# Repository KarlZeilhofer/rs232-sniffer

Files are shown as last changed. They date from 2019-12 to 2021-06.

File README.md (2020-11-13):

RS232 Sniffer
=============
KiCad Projekt der HTL-Steyr. 

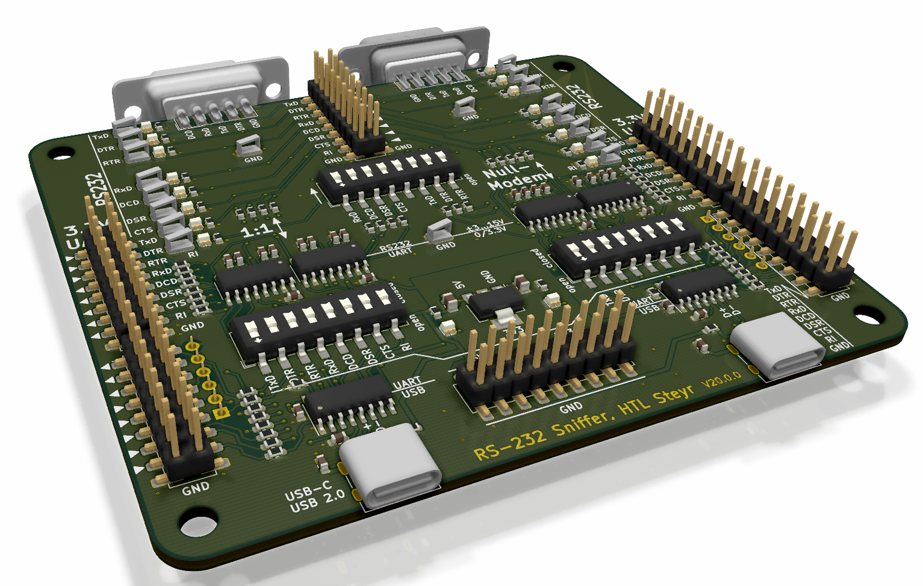
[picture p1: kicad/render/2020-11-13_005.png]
KiCad 3D Rendering


# Features
* MAX3232 für Pegelwandlung von 3.3 V auf RS232 (+-3...15 V)
* UART-Eingänge sind 5V-tolerant
* D-Sub9 Buchse Richtung PC (DTE)
* D-Sub9 Stecker Richtung Gerät (Modem, DCE)
* 2x USB-C Buchse (USB 2.0)
* 2x CH340 USB-UART-Umsetzer
* AM1117-3.3 (Linearregler für 3.3 V aus der 5V USB-Spannung)
* Signal-LEDs (grün = logisch High, rot = logisch Low)
* UART-Stiftleisten für Mikrocontroller
* Programmierbuchse für ESP32/ESP8266

# Anwendungsfälle
## RS232-Sniffer
RS232-Signale werden über D-Sub durchgeleitet. Man sieht dabei die Signal-LEDs entsprechend leuchten/blinken. 
Über die beiden USB-Anschlüsse bzw. die UART-Stiftleisten können die Daten aus beiden Richtungen mitgehorcht werden

## Protokollumsetzer
Die Verbindung der beiden D-Sub Steckverbinder kann aufgetrennt werden, und die Daten können über eine MCU oder einen PC umgeleitet werden. 
Somit können Protokolle angepasst werden bzw. Daten manipuliert werden. 

## USB-UART Adapter
Solche sind zwei Stück verbaut und können auch dirket als solche verwendet werden. 

# Hinweise
## Fertigung
* SMD-Schablone: 120um Dicke, 25mm umlaufender Rand für Pastendrucker
* Leiterplatte: 2 Layer, je 35um Cu, 103x90mm, d=1.6mm, beidseitig Bestückungsdruck
* Lötstopfreistellung: 51um
* min. Lötstopstegbreite: 100um
* Pastenreduktion: umlaufend 40um
* Durchkontaktierungen: blank (nicht mit Lötstopplack bedeckt)

## Besonderes
* Pads der USB-Buchsen wurden minimal verschmälert, um einen Lötstopplack zwischen die Pads zu bekommen.

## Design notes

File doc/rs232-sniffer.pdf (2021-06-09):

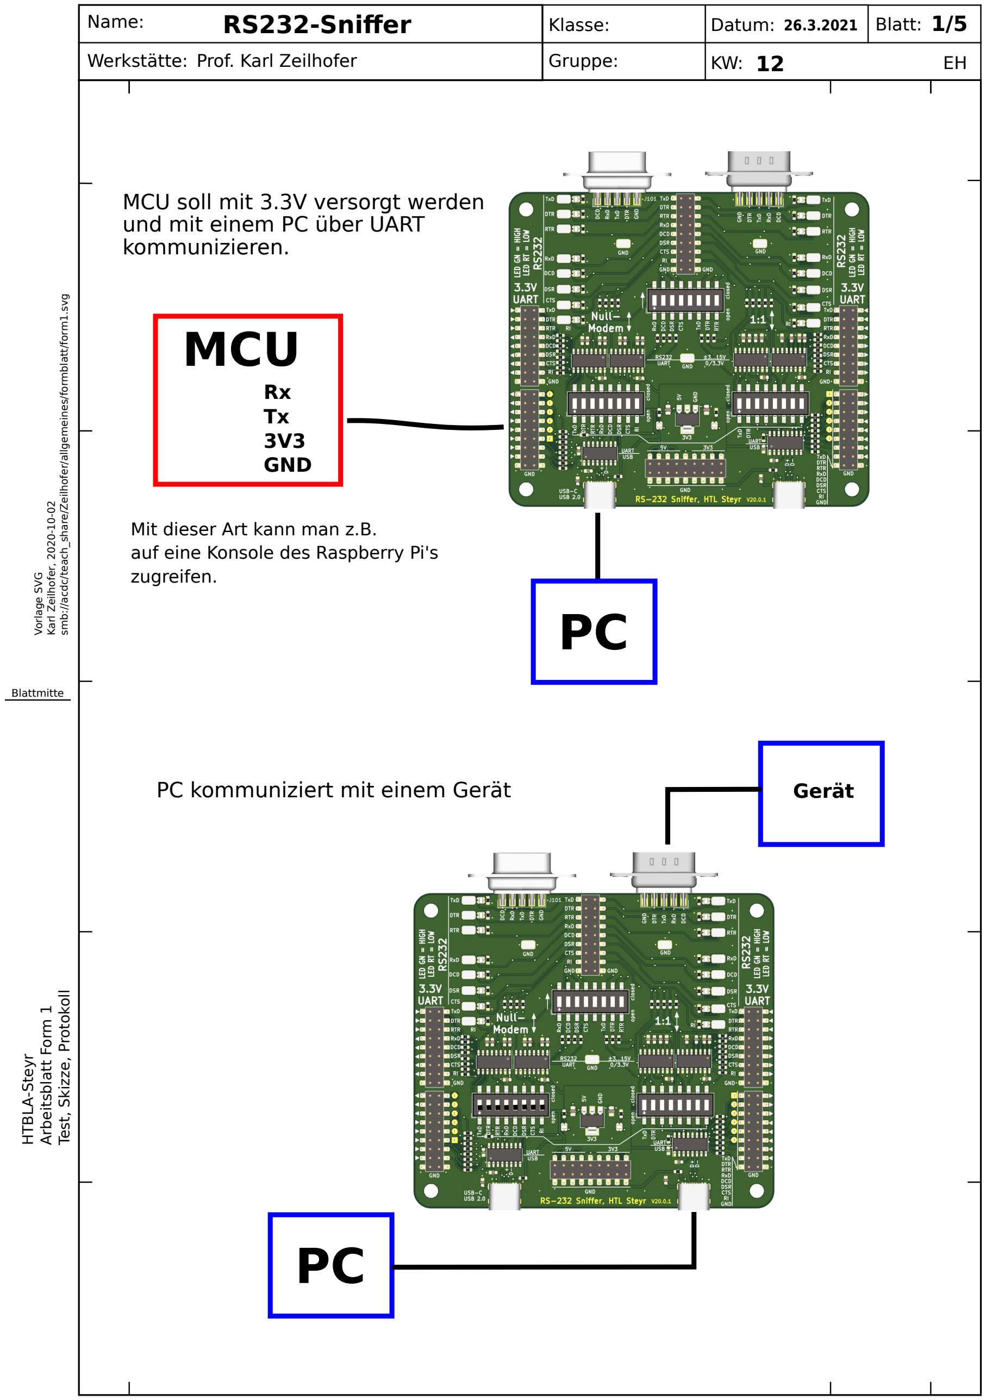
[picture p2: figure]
HTBLA-Steyr; Arbeitsblatt Form 1; Test, Skizze, Protokoll; Vorlage SVG; Karl Zeilhofer, 2020-10-02; Blattmitte; MCU; Rx Tx 3V3 GND; MCU soll mit 3.3V versorgt werden und mit einem PC über UART kommunizieren.; Gerät; PC kommuniziert mit einem Gerät; Mit dieser Art kann man z.B. auf eine Konsole des Raspberry Pi's zugreifen.

Name: RS232-Sniffer | Klasse: | 26.3.2021 Datum: | 1/5 Blatt:
Werkstätte: Prof. Karl Zeilhofer | Gruppe: | KW: 12 EH

smb://acdc/teach_share/Zeilhofer/allgemeines/formblatt/form1.svg

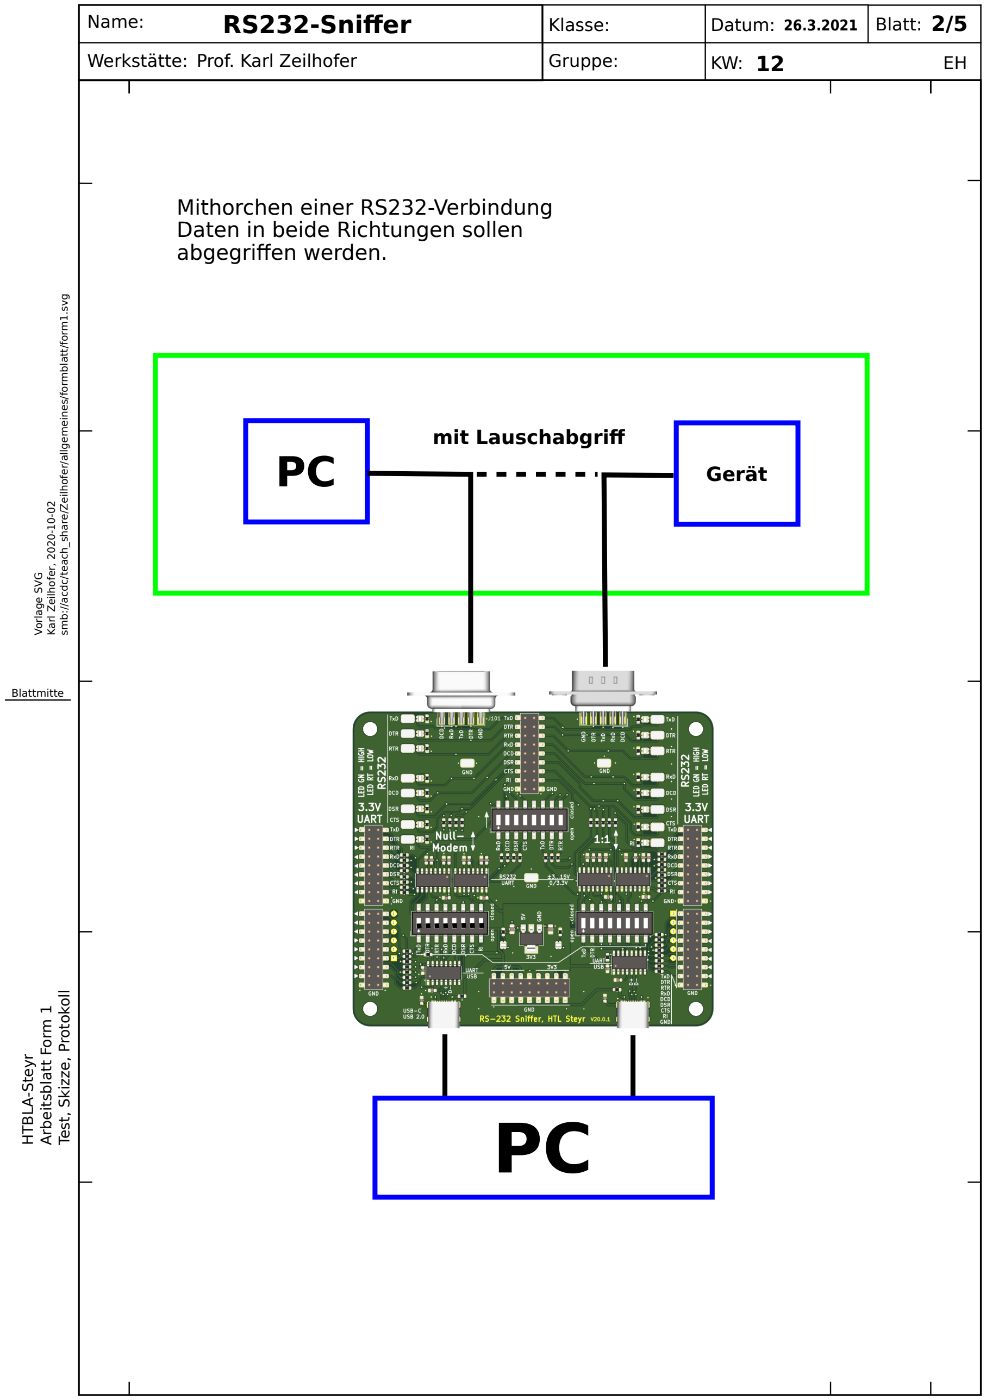
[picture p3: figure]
HTBLA-Steyr; Arbeitsblatt Form 1; Test, Skizze, Protokoll; Vorlage SVG; Karl Zeilhofer, 2020-10-02; Blattmitte; Gerät; mit Lauschabgriff; Mithorchen einer RS232-Verbindung Daten in beide Richtungen sollen abgegriffen werden.

smb://acdc/teach_share/Zeilhofer/allgemeines/formblatt/form1.svg

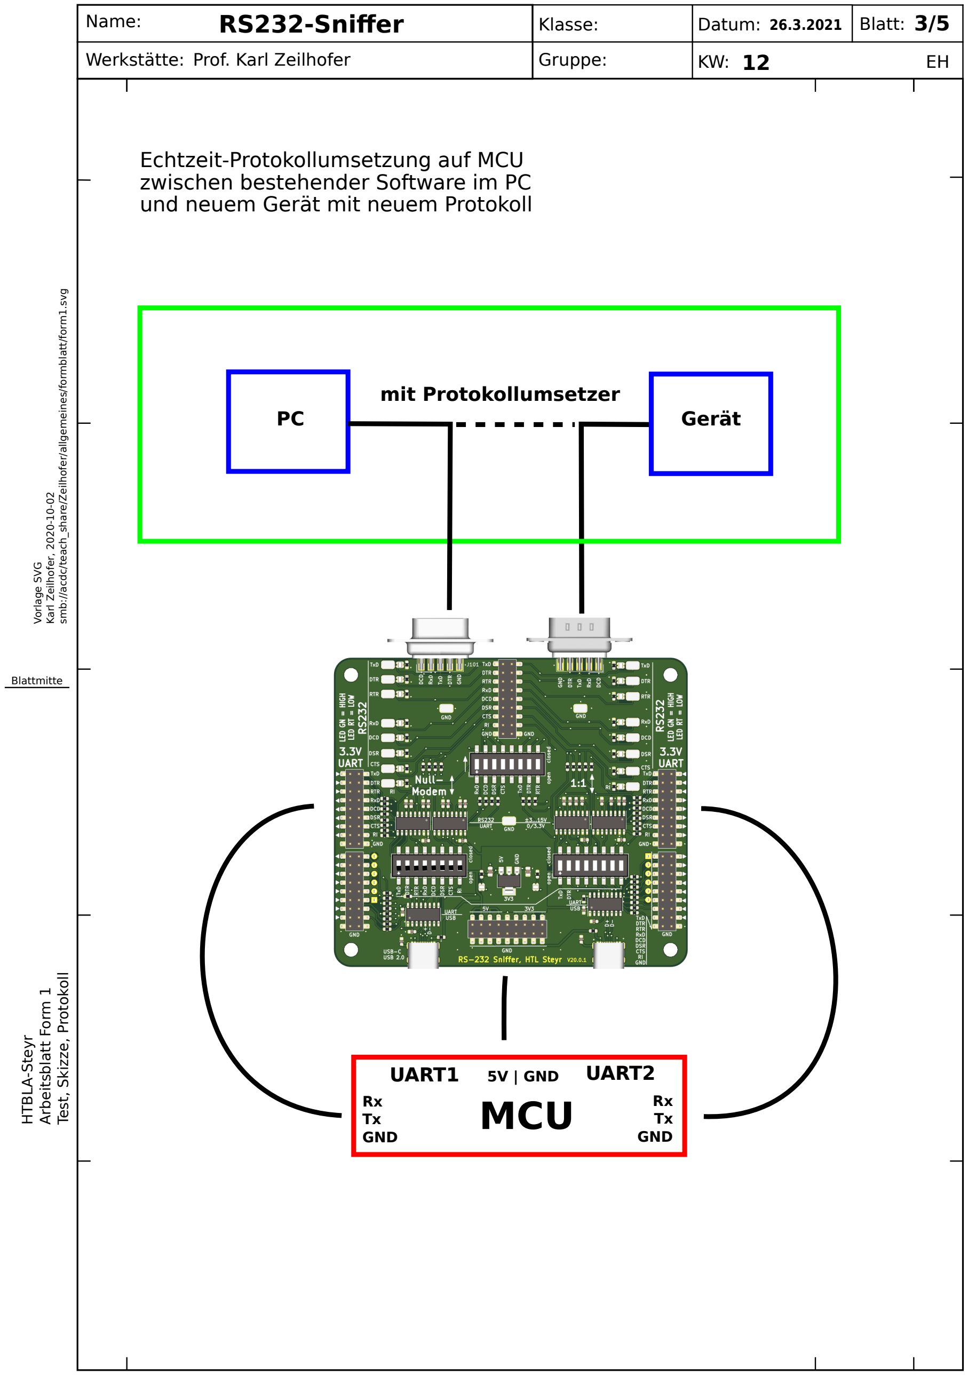
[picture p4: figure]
HTBLA-Steyr; Arbeitsblatt Form 1; Test, Skizze, Protokoll; Vorlage SVG; Karl Zeilhofer, 2020-10-02; Blattmitte; Echtzeit-Protokollumsetzung auf MCU zwischen bestehender Software im PC und neuem Gerät mit neuem Protokoll; MCU; Gerät; UART1; UART2; mit Protokollumsetzer; Rx Tx GND; 5V | GND

smb://acdc/teach_share/Zeilhofer/allgemeines/formblatt/form1.svg

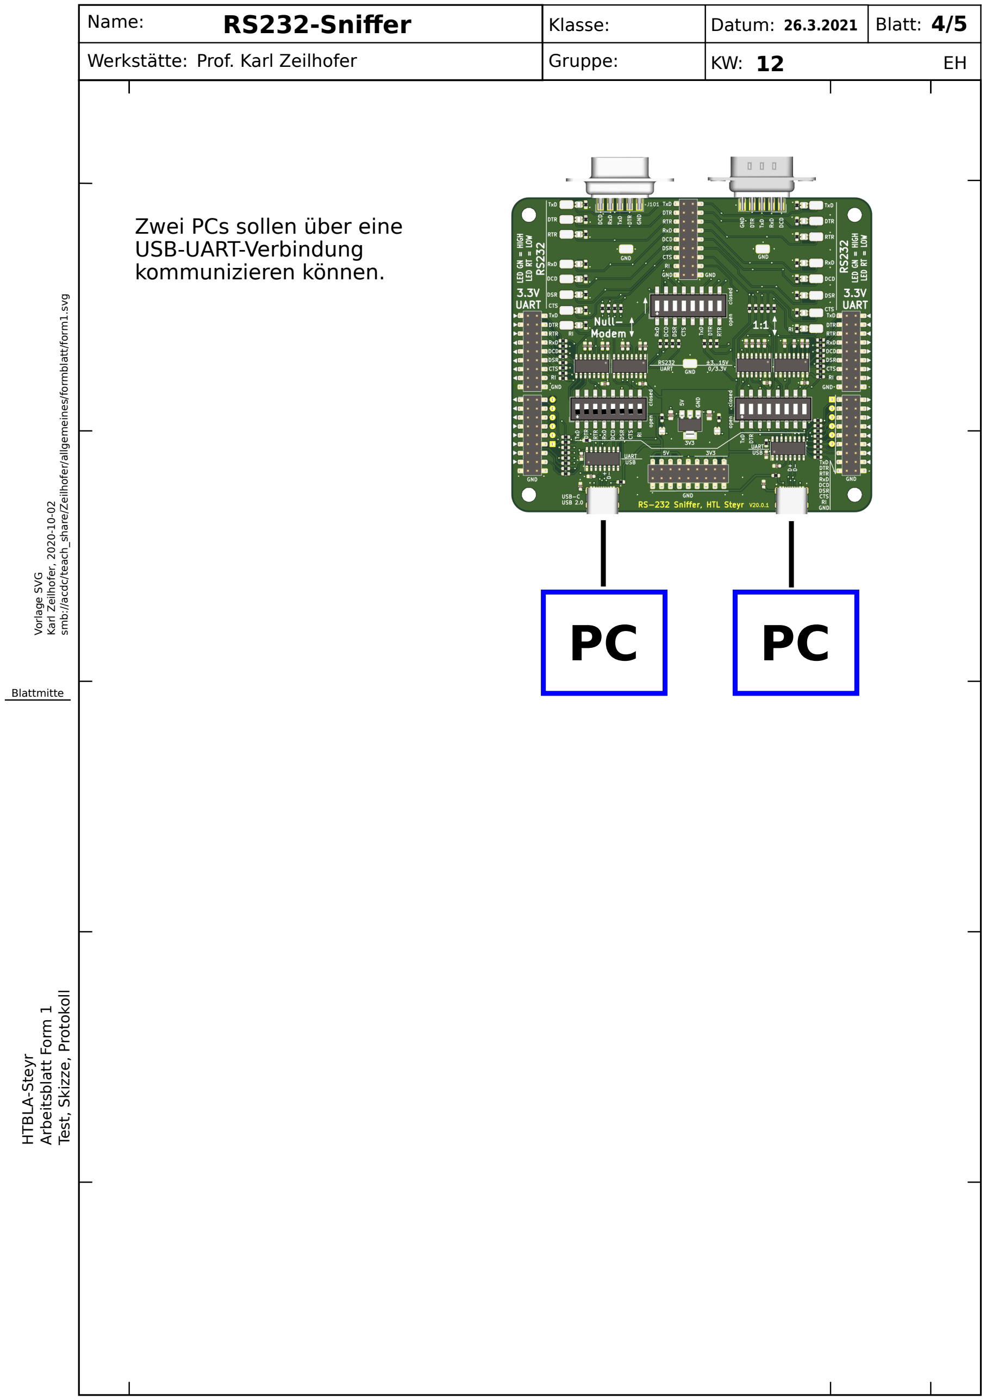
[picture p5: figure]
HTBLA-Steyr; Arbeitsblatt Form 1; Test, Skizze, Protokoll; Vorlage SVG; Karl Zeilhofer, 2020-10-02; Blattmitte; Zwei PCs sollen über eine USB-UART-Verbindung kommunizieren können.

smb://acdc/teach_share/Zeilhofer/allgemeines/formblatt/form1.svg

5/5

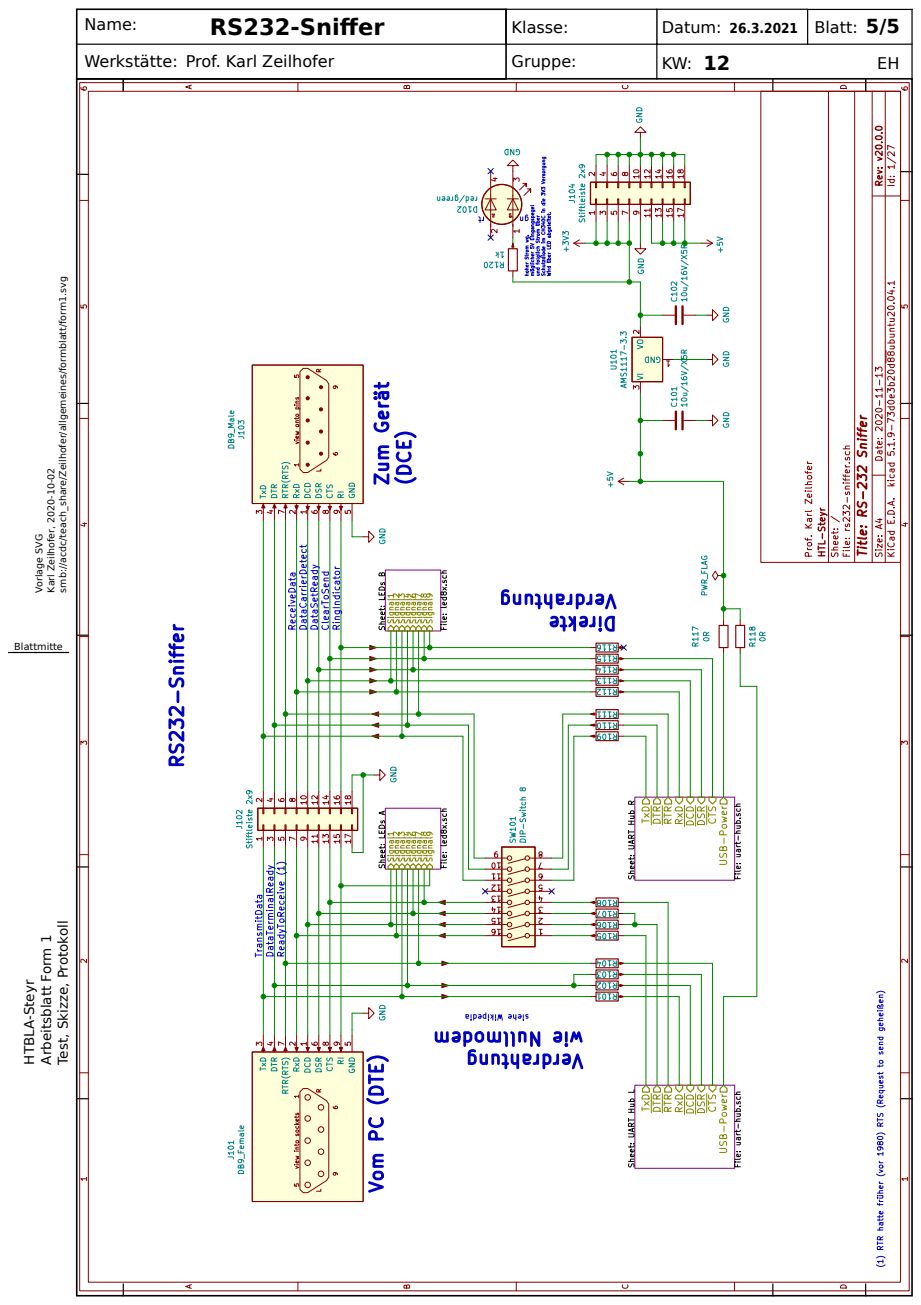
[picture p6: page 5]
HTBLA-Steyr; Arbeitsblatt Form 1; Vorlage SVG; Karl Zeilhofer, 2020-10-02; Blattmitte

smb://acdc/teach_share/Zeilhofer/allgemeines/formblatt/form1.svg

Test, Skizze, Protokoll

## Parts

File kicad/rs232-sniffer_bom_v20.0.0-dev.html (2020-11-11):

Source File | rs232-sniffer.sch
BoM Date | 2020-10-13T15:02:40 CEST
Schematic Version | v20.0.0-dev
Schematic Date | 2020-10-09
PCB Variant | [u'default']
KiCad Version | Eeschema 5.1.6-c6e7f7d~87~ubuntu18.04.1
Component Groups | 19
Component Count (per PCB) | 146
Fitted Components (per PCB) | 146
Number of PCBs | 1
Total Component Count (for 1 PCBs) | 146
 | Description | Part | References | Value | Footprint | Quantity Per PCB | Datasheet | Weblink | DistOrderNr | PriceForQty | PriceEUR | Distributor | ManPartNr | Manufacturer | Notes
1 | Unpolarized capacitor | C | C2501 C2502 C2503 C2504 C2505 C2506 C2601 C2602 C2603 C2604 C2605 C2606 C2607 C2608 C2609 C2610 C2701 C2702 C2703 C2704 C2705 C2706 C2707 C2708 C2709 C2710 | 100n | C_0603_1608Metric | 26 | https://datasheet.lcsc.com/szlcsc/1811151136_Walsin-Tech-Corp-0603B104K160CT_C80516.pdf | https://lcsc.com/product-detail/Multilayer-Ceramic-Capacitors-MLCC-SMD-SMT_Walsin-Tech-Corp-0603B104K160CT_C80516.html | C80516 | 500 | 0.002141 | LCSC | 0603B104K160CT | Walsin Tech Corp | 100nF ±10% 16V X7R
2 | Unpolarized capacitor | C | C101 C102 | 10u/16V/X5R | C_0805_2012Metric | 2 | https://datasheet.lcsc.com/szlcsc/1811151151_Samsung-Electro-Mechanics-CL21A106KOQNNNE_C1713.pdf | https://lcsc.com/product-detail/Multilayer-Ceramic-Capacitors-MLCC-SMD-SMT_SAMSUNG_CL21A106KOQNNNE_10uF-106-10-16V_C1713.html | C1713 | 200 | 0.011386 | LCSC | CL21A106KOQNNNE | Samsung | 10uF ±10% 16V X5R
3 | Dual LED, cathodes on pins 3 and 4 | LED_Dual_AACC | D101 D102 D301 D401 D501 D601 D701 D801 D901 D1001 D1201 D1301 D1401 D1501 D1601 D1701 D1801 D1901 | red/green | LED_LiteOn_LTST-C195KGJRKT | 18 | https://datasheet.lcsc.com/szlcsc/1811100910_Lite-On-LTST-C195KGJRKT_C125104.pdf | https://lcsc.com/product-detail/Light-Emitting-Diodes-LED_Lite-On-LTST-C195KGJRKT_C125104.html | C125104 | 1000 | 0.023 | LCSC | LTST-C195KGJRKT | LiteOn | Dual LED
4 | Virtual Item for accessories which should be listed in the BOM | Item | Item1 Item2 Item3 Item4 Item5 Item6 Item7 Item8 | Jumper | ~ | 8 | https://datasheet.lcsc.com/szlcsc/1811132212_BOOMELE-Boom-Precision-Elec-C5305_C5305.pdf | https://lcsc.com/product-detail/Shunts-Jumpers_BOOMELE-Boom-Precision-Elec-C5305_C5305.html | C5305 | 500 | 0.00319 | LCSC | C5305 | BOOMELE(Boom Precision Elec) | Jumper, 2.54mm
5 | Generic connector, single row, 01x06, script generated (kicad-library-utils/schlib/autogen/connector/) | Conn_01x06 | J2402 J2405 | Buchsenleiste 1x6, horizontal | PinSocket_1x06_P2.54mm_Horizontal | 2
6 | 9-pin male D-SUB connector | RS232_DB9_Female | J101 | DB9_Female | DSUB-9_Female_EdgeMount_P2.77mm | 1 | https://datasheet.lcsc.com/szlcsc/1811081030_CONNFLY-Elec-DS1033-09FUNSiSS-CT_C75748.pdf | https://lcsc.com/product-detail/D-Sub-Connectors_D-SUB-9pin-Female-blue-Welded-wire-type-Tin-plating-Without-screws_C75748.html | C75748 | 150 | 0.063911 | LCSC | DS1033-09FUNSiSS-CT | CONNFLY Elec | RS232 weiblich
7 | 9-pin male D-SUB connector | RS232_DB9_Male | J103 | DB9_Male | DSUB-9_Male_EdgeMount_P2.77mm | 1 |  | https://lcsc.com/product-detail/D-Sub-Connectors_D-SUB-9pin-Male-head-blue-Welded-wire-type-Tin-plating-Without-screws_C75746.html | C75746 | 150 | 0.059745 | LCSC | DS1033-09MUNSiSS | CONNFLY Elec | RS232 männlich
8 | Generic connector, double row, 02x09, odd/even pin numbering scheme (row 1 odd numbers, row 2 even numbers), script generated (kicad-library-utils/schlib/autogen/connector/) | Conn_02x09_Odd_Even | J102 J104 J2001 J2002 J2401 J2403 | Stiftleiste 2x9 | PinHeader_2x09_P2.54mm_Vertical_SMD | 6 |  | https://lcsc.com/product-detail/Pin-Header-Female-Header_BOOMELE-Boom-Precision-Elec-C88175_C88175.html | C88175 | 100 | 0.036 | LCSC | C88175 | BOOMELE(Boom Precision Elec) | SMD
9 | USB 2.0-only Type-C Receptacle connector | USB_C_Receptacle_USB2.0 | J2501 J2502 | USB-C/16p | USB_C_Receptacle_LCSC_C167321 | 2 | https://www.usb.org/sites/default/files/documents/usb_type-c.zip | https://lcsc.com/product-detail/USB-Connectors_Jing-Extension-of-the-Electronic-Co-C167321_C167321.html | C167321 | 100 | 0.155 | LCSC | C167321 | Jing Extension | USB-C, 16-polig, USB 2.0
10 | Resistor | R | R118 R120 | 0R | R_0603_1608Metric | 2 |  |  |  |  |  | LCSC
11 |  | R_sig | R105 R106 R107 R108 R109 R110 R111 R112 R114 R115 R116 R117 R119 R121 R122 R123 R2004 R2005 R2006 R2007 R2008 R2403 R2404 R2406 R2409 R2410 R2411 R2420 R2421 R2422 R2423 R2424 | 100R | R_0603_1608Metric | 32 | https://datasheet.lcsc.com/szlcsc/Uniroyal-Elec-0603WAJ0101T5E_C25201.pdf | https://lcsc.com/product-detail/Chip-Resistor-Surface-Mount_UNI-ROYAL-Uniroyal-Elec-0603WAJ0101T5E_C25201.html | C25201 | 1000 | 0.000563 | LCSC | 0603WAJ0101T5E | UNI-ROYAL | 100R, 5%, 100mW
12 | Resistor | R | R2501 R2502 | 100R | R_0603_1608Metric | 2 | https://datasheet.lcsc.com/szlcsc/Uniroyal-Elec-0603WAJ0101T5E_C25201.pdf | https://lcsc.com/product-detail/Chip-Resistor-Surface-Mount_UNI-ROYAL-Uniroyal-Elec-0603WAJ0101T5E_C25201.html | C25201 | 1000 | 0.000563 | LCSC | 0603WAJ0101T5E | UNI-ROYAL | 100R, 5%, 100mW
13 |  | R_sig | R113 R2001 R2002 R2003 R2401 R2402 R2405 R2407 R2408 R2412 R2413 R2414 R2415 R2416 R2417 R2418 R2419 | 1k | R_0603_1608Metric | 17 |  | https://lcsc.com/product-detail/Chip-Resistor-Surface-Mount_1KR-102-5_C103209.html | C103209 | 1000 | 0.000556 | LCSC | RTT03102JTP | RALEC | 1kΩ ±5% 0.1W ±100ppm/℃
14 | Resistor | R | R301 R401 R501 R601 R701 R801 R901 R1001 R1201 R1301 R1401 R1501 R1601 R1701 R1801 R1901 | 4k7 | R_0603_1608Metric | 16 | https://datasheet.lcsc.com/szlcsc/1809261316_RALEC-RTT03472JTP_C103662.pdf | https://lcsc.com/product-detail/Chip-Resistor-Surface-Mount_RALEC-RTT03472JTP_C103662.html | C103662 | 1000 | 0.000527 | LCSC | RTT03472JTP | RALEC | 4.7kΩ ±5% 0.1W ±100ppm/℃
15 |  | R_sig | R104 | 4k7 | R_0603_1608Metric | 1 | https://datasheet.lcsc.com/szlcsc/1809261316_RALEC-RTT03472JTP_C103662.pdf | https://lcsc.com/product-detail/Chip-Resistor-Surface-Mount_RALEC-RTT03472JTP_C103662.html | C103662 | 1000 | 0.000527 | LCSC | RTT03472JTP | RALEC | 4.7kΩ ±5% 0.1W ±100ppm/℃
16 | 8x DIP Switch, Single Pole Single Throw (SPST) switch, small symbol | SW_DIP_x08 | SW101 SW2401 SW2402 | DIP-Switch 8 | SW_DIP_SPSTx08_Slide_6.7x21.88mm_W8.61mm_P2.54mm_LowProfile | 3 | https://datasheet.lcsc.com/szlcsc/Made-in-China-HAD-08HWA-R_C4682.pdf | https://lcsc.com/product-detail/DIP-Switches_Cixi-Tonver-Elec-HAD-08HWA-R_C4682.html | C4682 | 100 | 0.262623 | LCSC | HAD-08HWA-R | Cixi Tonver Elec | SMD DIP-Switch
17 | 1A Low Dropout regulator, positive, 3.3V fixed output, SOT-223 | AMS1117-3.3 | U101 | AMS1117-3.3 | SOT-223-3_TabPin2 | 1 | http://www.advanced-monolithic.com/pdf/ds1117.pdf | https://lcsc.com/products/Dropout-Regulators-LDO_387.html?q=ams1117-3.3 | C347222 | 100 | 0.023029 | LCSC | AMS1117-3.3 | UMW Youtai Semiconductor | LDO, 3.3V
18 | USB serial converter, UART, SOIC-16 | CH340C | U2501 U2502 | CH340C | SOIC-16_3.9x9.9mm_P1.27mm | 2 | http://www.datasheet5.com/pdf-local-2195953 | https://lcsc.com/product-detail/USB-ICs_WCH-Jiangsu-Qin-Heng-CH340C_C84681.html | C84681 | 100 | 0.239 | LCSC | CH340C | WCH(Jiangsu Qin Heng) | USB-UART with internal clock
19 | 3.0V to 5.5V, Low-Power, up to 1Mbps, True RS-232 Transceivers Using Four 0.1μF External Capacitors | MAX3232 | U2601 U2602 U2701 U2702 | MAX3232 | SOIC-16_3.9x9.9mm_P1.27mm | 4 | https://datasheets.maximintegrated.com/en/ds/MAX3222-MAX3241.pdf | https://lcsc.com/product-detail/Uncategorized_HGSEMI-MAX3232EIM-TR_C434486.html | C434486 | 100 | 0.188404 | LCSC | MAX3232EIM/TR | HGSEMI | RS232 - UART Umsetzer, 3V3 oder 5V

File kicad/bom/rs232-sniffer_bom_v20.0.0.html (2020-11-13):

Source File | rs232-sniffer.sch
BoM Date | 2020-11-13T16:51:07 CET
Schematic Version | v20.0.0
Schematic Date | 2020-11-13
PCB Variant | [u'default']
KiCad Version | Eeschema 5.1.6-c6e7f7d~87~ubuntu18.04.1
Component Groups | 19
Component Count (per PCB) | 146
Fitted Components (per PCB) | 146
Number of PCBs | 1
Total Component Count (for 1 PCBs) | 146
 | Description | Part | References | Value | Footprint | Quantity Per PCB | Datasheet | Weblink | DistOrderNr | PriceForQty | PriceEUR | Distributor | ManPartNr | Manufacturer | Notes
1 | Unpolarized capacitor | C | C2501 C2502 C2503 C2504 C2505 C2506 C2601 C2602 C2603 C2604 C2605 C2606 C2607 C2608 C2609 C2610 C2701 C2702 C2703 C2704 C2705 C2706 C2707 C2708 C2709 C2710 | 100n | C_0603_1608Metric | 26 | https://datasheet.lcsc.com/szlcsc/1811151136_Walsin-Tech-Corp-0603B104K160CT_C80516.pdf | https://lcsc.com/product-detail/Multilayer-Ceramic-Capacitors-MLCC-SMD-SMT_Walsin-Tech-Corp-0603B104K160CT_C80516.html | C80516 | 500 | 0.002141 | LCSC | 0603B104K160CT | Walsin Tech Corp | 100nF ±10% 16V X7R
2 | Unpolarized capacitor | C | C101 C102 | 10u/16V/X5R | C_0805_2012Metric | 2 | https://datasheet.lcsc.com/szlcsc/1811151151_Samsung-Electro-Mechanics-CL21A106KOQNNNE_C1713.pdf | https://lcsc.com/product-detail/Multilayer-Ceramic-Capacitors-MLCC-SMD-SMT_SAMSUNG_CL21A106KOQNNNE_10uF-106-10-16V_C1713.html | C1713 | 200 | 0.011386 | LCSC | CL21A106KOQNNNE | Samsung | 10uF ±10% 16V X5R
3 | Dual LED, cathodes on pins 3 and 4 | LED_Dual_green-red | D101 D102 D301 D401 D501 D601 D701 D801 D901 D1001 D1201 D1301 D1401 D1501 D1601 D1701 D1801 D1901 | red/green | LED_LiteOn_LTST-C195KGJRKT | 18 | https://datasheet.lcsc.com/szlcsc/1811100910_Lite-On-LTST-C195KGJRKT_C125104.pdf | https://lcsc.com/product-detail/Light-Emitting-Diodes-LED_Lite-On-LTST-C195KGJRKT_C125104.html | C125104 | 1000 | 0.023 | LCSC | LTST-C195KGJRKT | LiteOn | Dual LED
4 | Virtual Item for accessories which should be listed in the BOM | Item | Item101 Item102 Item103 Item104 Item105 Item106 Item107 Item108 | Jumper | ~ | 8 | https://datasheet.lcsc.com/szlcsc/1811132212_BOOMELE-Boom-Precision-Elec-C5305_C5305.pdf | https://lcsc.com/product-detail/Shunts-Jumpers_BOOMELE-Boom-Precision-Elec-C5305_C5305.html | C5305 | 500 | 0.00319 | LCSC | C5305 | BOOMELE(Boom Precision Elec) | Jumper, 2.54mm
5 | Generic connector, single row, 01x06, script generated (kicad-library-utils/schlib/autogen/connector/) | Conn_01x06 | J2402 J2405 | Buchsenleiste 1x6, horizontal | PinSocket_1x06_P2.54mm_Horizontal | 2
6 | 9-pin male D-SUB connector | RS232_DB9_Female | J101 | DB9_Female | DSUB-9_Female_EdgeMount_P2.77mm | 1 | https://datasheet.lcsc.com/szlcsc/1811081030_CONNFLY-Elec-DS1033-09FUNSiSS-CT_C75748.pdf | https://lcsc.com/product-detail/D-Sub-Connectors_D-SUB-9pin-Female-blue-Welded-wire-type-Tin-plating-Without-screws_C75748.html | C75748 | 150 | 0.063911 | LCSC | DS1033-09FUNSiSS-CT | CONNFLY Elec | RS232 weiblich
7 | 9-pin male D-SUB connector | RS232_DB9_Male | J103 | DB9_Male | DSUB-9_Male_EdgeMount_P2.77mm | 1 |  | https://lcsc.com/product-detail/D-Sub-Connectors_D-SUB-9pin-Male-head-blue-Welded-wire-type-Tin-plating-Without-screws_C75746.html | C75746 | 150 | 0.059745 | LCSC | DS1033-09MUNSiSS | CONNFLY Elec | RS232 männlich
8 | Generic connector, double row, 02x09, odd/even pin numbering scheme (row 1 odd numbers, row 2 even numbers), script generated (kicad-library-utils/schlib/autogen/connector/) | Conn_02x09_Odd_Even | J102 J104 J2001 J2002 J2401 J2403 | Stiftleiste 2x9 | PinHeader_2x09_P2.54mm_Vertical_SMD_LCSC_C88175 | 6 |  | https://lcsc.com/product-detail/Pin-Header-Female-Header_BOOMELE-Boom-Precision-Elec-C88175_C88175.html | C88175 | 100 | 0.036 | LCSC | C88175 | BOOMELE(Boom Precision Elec) | SMD
9 | USB 2.0-only Type-C Receptacle connector | USB_C_Receptacle_USB2.0 | J2501 J2502 | USB-C/16p | USB_C_Receptacle_LCSC_C167321 | 2 | https://www.usb.org/sites/default/files/documents/usb_type-c.zip | https://lcsc.com/product-detail/USB-Connectors_Jing-Extension-of-the-Electronic-Co-C167321_C167321.html | C167321 | 100 | 0.155 | LCSC | C167321 | Jing Extension | USB-C, 16-polig, USB 2.0
10 | Resistor | R | R117 R118 | 0R | R_0603_1608Metric | 2 |  |  |  |  |  | LCSC
11 |  | R_sig | R101 R102 R103 R104 R105 R106 R107 R108 R109 R110 R111 R112 R113 R114 R115 R116 R2004 R2005 R2006 R2007 R2008 R2403 R2404 R2406 R2409 R2410 R2411 R2420 R2421 R2422 R2423 R2424 | 100R | R_0603_1608Metric | 32 | https://datasheet.lcsc.com/szlcsc/Uniroyal-Elec-0603WAJ0101T5E_C25201.pdf | https://lcsc.com/product-detail/Chip-Resistor-Surface-Mount_UNI-ROYAL-Uniroyal-Elec-0603WAJ0101T5E_C25201.html | C25201 | 1000 | 0.000563 | LCSC | 0603WAJ0101T5E | UNI-ROYAL | 100R, 5%, 100mW
12 | Resistor | R | R2501 R2502 | 100R | R_0603_1608Metric | 2 | https://datasheet.lcsc.com/szlcsc/Uniroyal-Elec-0603WAJ0101T5E_C25201.pdf | https://lcsc.com/product-detail/Chip-Resistor-Surface-Mount_UNI-ROYAL-Uniroyal-Elec-0603WAJ0101T5E_C25201.html | C25201 | 1000 | 0.000563 | LCSC | 0603WAJ0101T5E | UNI-ROYAL | 100R, 5%, 100mW
13 |  | R_sig | R120 R2001 R2002 R2003 R2401 R2402 R2405 R2407 R2408 R2412 R2413 R2414 R2415 R2416 R2417 R2418 R2419 | 1k | R_0603_1608Metric | 17 |  | https://lcsc.com/product-detail/Chip-Resistor-Surface-Mount_1KR-102-5_C103209.html | C103209 | 1000 | 0.000556 | LCSC | RTT03102JTP | RALEC | 1kΩ ±5% 0.1W ±100ppm/℃
14 | Resistor | R | R301 R401 R501 R601 R701 R801 R901 R1001 R1201 R1301 R1401 R1501 R1601 R1701 R1801 R1901 | 4k7 | R_0603_1608Metric | 16 | https://datasheet.lcsc.com/szlcsc/1809261316_RALEC-RTT03472JTP_C103662.pdf | https://lcsc.com/product-detail/Chip-Resistor-Surface-Mount_RALEC-RTT03472JTP_C103662.html | C103662 | 1000 | 0.000527 | LCSC | RTT03472JTP | RALEC | 4.7kΩ ±5% 0.1W ±100ppm/℃
15 |  | R_sig | R119 | 4k7 | R_0603_1608Metric | 1 | https://datasheet.lcsc.com/szlcsc/1809261316_RALEC-RTT03472JTP_C103662.pdf | https://lcsc.com/product-detail/Chip-Resistor-Surface-Mount_RALEC-RTT03472JTP_C103662.html | C103662 | 1000 | 0.000527 | LCSC | RTT03472JTP | RALEC | 4.7kΩ ±5% 0.1W ±100ppm/℃
16 | 8x DIP Switch, Single Pole Single Throw (SPST) switch, small symbol | SW_DIP_x08 | SW101 SW2401 SW2402 | DIP-Switch 8 | SW_DIP_SPSTx08_Slide_6.7x21.88mm_W8.61mm_P2.54mm_LowProfile | 3 | https://datasheet.lcsc.com/szlcsc/Made-in-China-HAD-08HWA-R_C4682.pdf | https://lcsc.com/product-detail/DIP-Switches_Cixi-Tonver-Elec-HAD-08HWA-R_C4682.html | C4682 | 100 | 0.262623 | LCSC | HAD-08HWA-R | Cixi Tonver Elec | SMD DIP-Switch
17 | 1A Low Dropout regulator, positive, 3.3V fixed output, SOT-223 | AMS1117-3.3 | U101 | AMS1117-3.3 | SOT-223-3_TabPin2 | 1 | http://www.advanced-monolithic.com/pdf/ds1117.pdf | https://lcsc.com/products/Dropout-Regulators-LDO_387.html?q=ams1117-3.3 | C347222 | 100 | 0.023029 | LCSC | AMS1117-3.3 | UMW Youtai Semiconductor | LDO, 3.3V
18 | USB serial converter, UART, SOIC-16 | CH340C | U2501 U2502 | CH340C | SOIC-16_3.9x9.9mm_P1.27mm | 2 | http://www.datasheet5.com/pdf-local-2195953 | https://lcsc.com/product-detail/USB-ICs_WCH-Jiangsu-Qin-Heng-CH340C_C84681.html | C84681 | 100 | 0.239 | LCSC | CH340C | WCH(Jiangsu Qin Heng) | USB-UART with internal clock
19 | 3.0V to 5.5V, Low-Power, up to 1Mbps, True RS-232 Transceivers Using Four 0.1μF External Capacitors | MAX3232 | U2601 U2602 U2701 U2702 | MAX3232 | SOIC-16_3.9x9.9mm_P1.27mm | 4 | https://datasheets.maximintegrated.com/en/ds/MAX3222-MAX3241.pdf | https://lcsc.com/product-detail/Uncategorized_HGSEMI-MAX3232EIM-TR_C434486.html | C434486 | 100 | 0.188404 | LCSC | MAX3232EIM/TR | HGSEMI | RS232 - UART Umsetzer, 3V3 oder 5V

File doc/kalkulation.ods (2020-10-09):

 | RS |  |  |  | China |  |  | Notizen
 | Stück | Gesamt | Link RS | Stück | Stück | Gesamt | Link China | rfc
DB9 Stecker | 0,33 | 0,33 | https://at.rs-online.com/web/p/d-sub-steckverbinder/1217374 | 1 | 0,06 | 0,06 | https://lcsc.com/product-detail/D-Sub-Connectors_D-SUB-9pin-Male-head-blue-Welded-wire-type-Tin-plating-Without-screws_C75746.html | rfc
DB9 Buchse | 0,41 | 1,24 | https://at.rs-online.com/web/p/d-sub-steckverbinder/1372559 | 3 | 0,07 | 0,21 | https://lcsc.com/product-detail/D-Sub-Connectors_D-SUB-9pin-Female-blue-Welded-wire-type-Tin-plating-Without-screws_C75748.html | rfc
USB to UART | 1,83 | 3,66 | https://at.rs-online.com/web/p/asynchrone-receiver-transmitter/7570032 | 2 | 0,24 | 0,48 | https://www.ebay.at/itm/50-Stucke-CH340G-R3-Bord-Freies-Usb-Kabel-Serieller-Chip-Sop-kr/332195717913 | rfc
USB C Buchse | 4,07 | 8,14 |  | 2 | 0,15 | 0,30 | https://lcsc.com/product-detail/USB-Connectors_Jing-Extension-of-the-Electronic-Co-C167321_C167321.html | rfc
PCB, 60 Stk | 2,75 | 2,75 |  | 1 | 0,62 | 0,62 | PCB-Shopper | rfc
MAX3232 | 1,03 | 4,12 | https://at.rs-online.com/web/p/line-transceiver/1218440 | 4 | 0,18 | 0,72 | https://lcsc.com/product-detail/Uncategorized_HGSEMI-MAX3232EIM-TR_C434486.html | rfc
Dual-LED | 0,12 | 1,92 |  | 16 | 0,02 | 0,37 | https://lcsc.com/product-detail/Light-Emitting-Diodes-LED_Lite-On-LTST-C195KGJRKT_C125104.html | rfc
100nF |  | 0,00 |  | 10 | 0,00 | 0,02 | https://lcsc.com/product-detail/Multilayer-Ceramic-Capacitors-MLCC-SMD-SMT_Walsin-Tech-Corp-0603B104K160CT_C80516.html | rfc
AMS1117-3V3 |  | 0,00 |  | 1 | 0,02 | 0,02 | https://lcsc.com/product-detail/Dropout-Regulators-LDO_UMW-Youtai-Semiconductor-Co-Ltd-AMS1117-3-3_C347222.html | rfc
 |  | 0,00 |  |  |  | 0,00 |  | rfc
 |  | 0,00 |  |  |  | 0,00 |  | rfc
 |  | 0,00 |  |  |  | 0,00 |  | rfc
 |  | 0,00 |  |  |  | 0,00 |  | rfc
 |  | 0,00 |  |  |  | 0,00 |  | rfc
 |  | 0,00 |  |  |  | 0,00 |  | rfc
 |  | 0,00 |  |  |  | 0,00 |  | rfc
Summe |  | 22,16 |  |  |  | 2,80 |  | rfc
Mit Ust |  | 26,60
Rabatt |  | 21,28

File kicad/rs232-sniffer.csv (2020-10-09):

Reference | Quantity | Value | Footprint | Datasheet | DistOrderNr | Distributor | ManPartNr | Manufacturer | Notes | PriceEUR | PriceForQty | Weblink
C202 C201 C2103 C2101 C2105 C2104 C2102 C2203 C2201 C2205 C2204 C2202 C2303 C2301 C2305 C2304 C2302 C2403 C2401 C2405 C2404 C2402 C2502 C2501 | 24 | 100n | Capacitor_SMD:C_0603_1608Metric | https://datasheet.lcsc.com/szlcsc/1811151136_Walsin-Tech-Corp-0603B104K160CT_C80516.pdf | C80516 | LCSC | 0603B104K160CT | Walsin Tech Corp | 100nF ±10% 16V X7R | 0.002141 | 500 | https://lcsc.com/product-detail/Multilayer-Ceramic-Capacitors-MLCC-SMD-SMT_Walsin-Tech-Corp-0603B104K160CT_C80516.html
D401 D501 D601 D701 D801 D901 D1001 D1101 D1301 D1401 D1501 D1601 D1701 D1801 D1901 D2001 | 16 | red/green | rs232-sniffer:LED_LiteOn_LTST-C195KGJRKT | https://datasheet.lcsc.com/szlcsc/1811100910_Lite-On-LTST-C195KGJRKT_C125104.pdf | C125104 | LCSC | LTST-C195KGJRKT | LiteOn | Dual LED | 0.023 | 1000 | https://lcsc.com/product-detail/Light-Emitting-Diodes-LED_Lite-On-LTST-C195KGJRKT_C125104.html
H101 H102 H103 H104 | 4 | MountingHole | MountingHole:MountingHole_4mm | ~ |  |  |  |  | NAP
J101 J102 J105 | 3 | DB9_Female | rs232-sniffer:DSUB-9_Female_Vertical_P2.77x2.84mm_MountingHoles | https://datasheet.lcsc.com/szlcsc/1811081030_CONNFLY-Elec-DS1033-09FUNSiSS-CT_C75748.pdf | C75748 | LCSC | DS1033-09FUNSiSS-CT | CONNFLY Elec | RS232 weiblich | 0.063911 | 150 | https://lcsc.com/product-detail/D-Sub-Connectors_D-SUB-9pin-Female-blue-Welded-wire-type-Tin-plating-Without-screws_C75748.html
J103 | 1 | Conn_02x05_Counter_Clockwise |  | ~
J104 | 1 | Stiftleiste 2x9 | rs232-sniffer:PinHeader_2x09_P2.54mm_Vertical_SMD | ~ | C88175 | LCSC | C88175 | BOOMELE(Boom Precision Elec) | SMD | 0.036 | 100 | https://lcsc.com/product-detail/Pin-Header-Female-Header_BOOMELE-Boom-Precision-Elec-C88175_C88175.html
J106 | 1 | Conn_02x03_Counter_Clockwise |  | ~
J107 | 1 | DB9_Male | rs232-sniffer:DSUB-9_Male_EdgeMount_P2.77mm_MountingHoles | ~ | C75746 | LCSC | DS1033-09MUNSiSS | CONNFLY Elec | RS232 männlich | 0.059745 | 150 | https://lcsc.com/product-detail/D-Sub-Connectors_D-SUB-9pin-Male-head-blue-Welded-wire-type-Tin-plating-Without-screws_C75746.html
J201 J2501 | 2 | USB-C/16p | rs232-sniffer:USB_C_Receptacle_LCSC_C167321 | https://www.usb.org/sites/default/files/documents/usb_type-c.zip | C167321 | LCSC | C167321 | Jing Extension | USB-C, 16-polig | 0.155 | 100 | https://lcsc.com/product-detail/USB-Connectors_Jing-Extension-of-the-Electronic-Co-C167321_C167321.html
R102 R101 R103 R122 R123 R121 R120 R124 R104 R113 R114 R115 R116 R105 R106 R112 R110 R109 R108 R119 R118 R117 R107 R111 R201 R2501 | 26 | 100R | Resistor_SMD:R_0603_1608Metric | https://datasheet.lcsc.com/szlcsc/Uniroyal-Elec-0603WAJ0101T5E_C25201.pdf | C25201 | LCSC | 0603WAJ0101T5E | UNI-ROYAL | 100R, 5%, 100mW | 0.000563 | 1000 | https://lcsc.com/product-detail/Chip-Resistor-Surface-Mount_UNI-ROYAL-Uniroyal-Elec-0603WAJ0101T5E_C25201.html
R401 R501 R601 R701 R801 R901 R1001 R1101 R1301 R1401 R1501 R1601 R1701 R1801 R1901 R2001 | 16 | 4k7 | Resistor_SMD:R_0603_1608Metric | https://datasheet.lcsc.com/szlcsc/1809261316_RALEC-RTT03472JTP_C103662.pdf | C103662 | LCSC | RTT03472JTP | RALEC | 4.7kΩ ±5% 0.1W ±100ppm/℃ | 0.000527 | 1000 | https://lcsc.com/product-detail/Chip-Resistor-Surface-Mount_RALEC-RTT03472JTP_C103662.html
TP101 TP102 TP103 TP401 TP501 TP601 TP701 TP801 TP901 TP1001 TP1101 TP1301 TP1401 TP1501 TP1601 TP1701 TP1801 TP1901 TP2001 | 19 | SMD Testpoint | rs232-sniffer:Keystone_5016 | https://datasheet.lcsc.com/szlcsc/1810151521_Keystone-5016_C238129.pdf | C238129 | LCSC | 5016 | Keystone | SMD Testöse | 0.084 | 1000 | https://lcsc.com/product-detail/Test-Points-Test-Rings_Keystone-5016_C238129.html
U201 U2501 | 2 | CH340C | Package_SO:SOIC-16_3.9x9.9mm_P1.27mm | http://www.datasheet5.com/pdf-local-2195953 | C84681 | LCSC | CH340C | WCH(Jiangsu Qin Heng) |  | 0.239 | 100 | https://lcsc.com/product-detail/USB-ICs_WCH-Jiangsu-Qin-Heng-CH340C_C84681.html
U2101 U2201 U2301 U2401 | 4 | MAX3232 |  | https://datasheets.maximintegrated.com/en/ds/MAX3222-MAX3241.pdf

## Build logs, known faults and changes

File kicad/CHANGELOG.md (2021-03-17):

Changelog zu RS232-Sniffer der HTL-Steyr
========================================

# V20.0.1
* Beschriftung Nullmodem und 1:1 vertauscht. Links ist die Nullmodem-Verdrahtung, rechts 1:1 (gerade). 
* Nun keine SMD-Paste bei den D-Sub-Steckverbindern
* Abstand der SMD-LED-Pads von 200um auf 300um vergrößert
* Dual-LED so gedreht, damit grün oben ist, rot unten (analog zu HIGH und LOW)
* LED-Farben auf Bestückungsdruck erklärt
* Versionslabel auf V20.0.1 aktualisiert
* ERC überprüft
* Gerber exportiert
* 30 Stk. PCBs + Maske TOP bestellt (Maske versehentlich mit 100um statt 120um Dicke bestellt)

# V20.0.0
Erster produzierter Prototyp, 14 Platinen

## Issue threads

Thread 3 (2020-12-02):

Status-LEDs um 90° Drehen

KarlZeilhofer, 2020-12-02:
Somit könnte die Grüne LED oben und die Rote LED unten sein, was etwas schöner wäre.

Rot = Low, Grün = High

KarlZeilhofer, 2021-03-17:
Wurde in V20.0.1 umgesetzt. Links nach links rotiert, rechts nach rechts rotiert.

Closed 2021-03-17.

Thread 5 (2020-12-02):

Pfeilrichtungen an der mittleren Jumper-Leiste falsch!

KarlZeilhofer, 2020-12-02:
zumindest trifft dies für die UART zu!

Evt. muss die linke und rechte UART-Schaltung vertauscht werden!

Für RS232 dürften die Pfeile nämlich passen.

KarlZeilhofer, 2021-03-17:
Die Pfeilchen wurden gelöscht, da sie nicht eindeutig sein können.

Closed 2021-03-17.

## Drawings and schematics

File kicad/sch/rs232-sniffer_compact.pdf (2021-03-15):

Vom PC (DTE) | DataCarrierDetect RS232-Sniffer

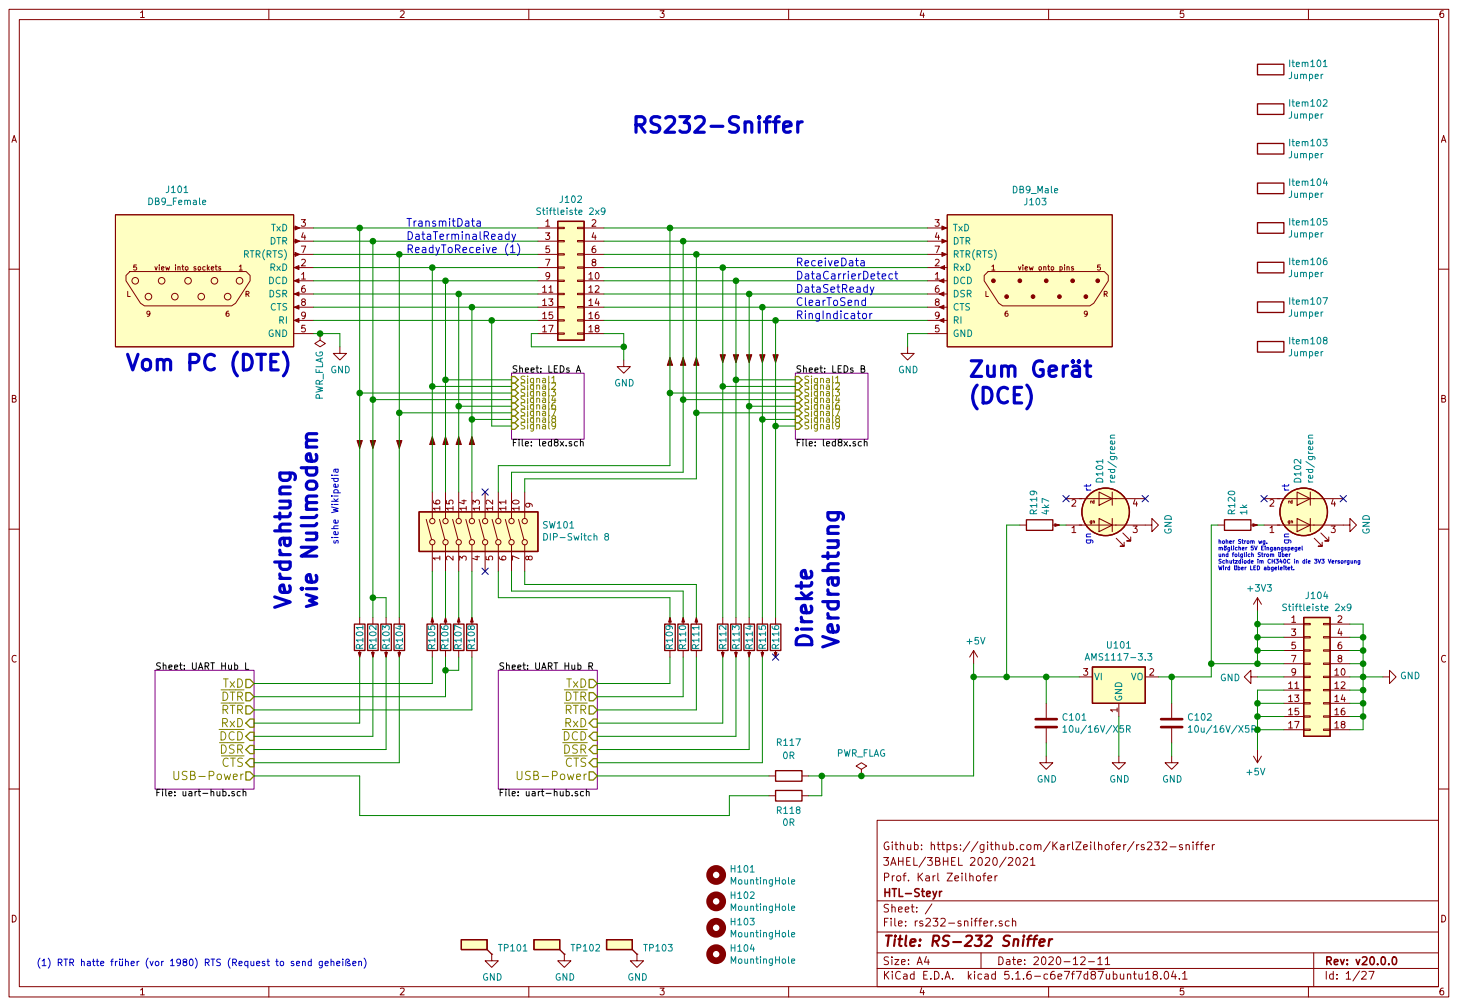
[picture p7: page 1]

DataTerminalReady TransmitData Verdrahtung wie Nullmodem

möglicher 5V Eingangspegel und folglich Strom über Schutzdiode im CH340C in die 3V3 Versorgung Wird über LED abgeleitet. ReceiveData ClearToSend
File: led8x.sch Signal1 Signal2 Signal3 Signal4 Signal6 Signal7 Signal8 Signal9 R117

Zum Gerät
(DCE)
4 D¹⁰¹ red/green GND

4 D¹⁰² red/green R¹¹⁹ 4k7

USB-Power Sheet: UART Hub L File: uart-hub.schDCD

Id: 1/27 Title: RS-232 Sniffer File: rs232-sniffer.sch Sheet: / HTL-Steyr Prof. Karl Zeilhofer 3AHEL/3BHEL 2020/2021 Github: https://github.com/KarlZeilhofer/rs232-sniffer Sheet: UART Hub R

File: uart-hub.schDCD

(1) RTR hatte früher (vor 1980) RTS (Request to send geheißen)

File: led.sch Signal Sheet: sheet5F813E84 File: led.sch Signal Sheet: sheet5F813BE0 File: led.sch Signal

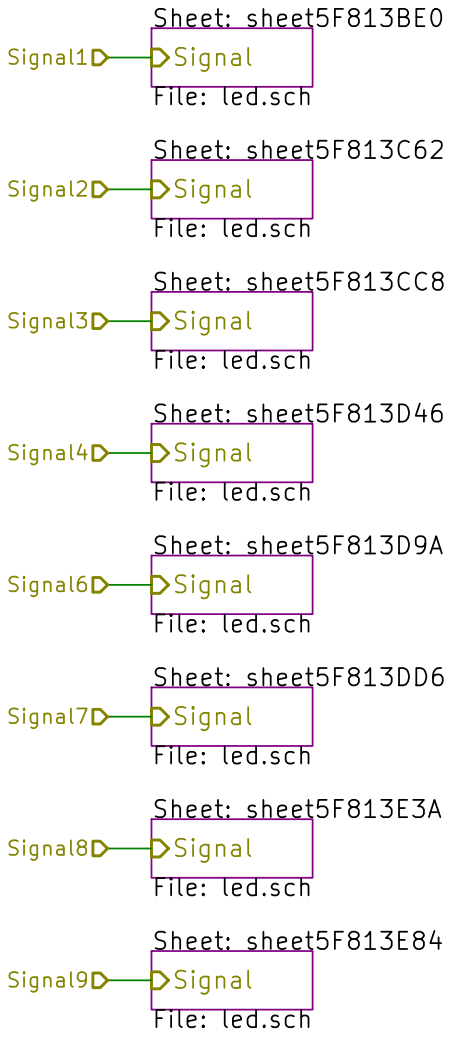
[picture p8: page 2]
D Date: 2020-12-11 KiCad E.D.A. kicad 5.1.6-c6e7f7d87ubuntu18.04.1 Size: A4; Rev: v20.0.0; Signal9; Signal8; Signal7; Signal6; Signal4; Signal3; Signal2; Signal1

Sheet: sheet5F813C62 File: led.sch Signal Sheet: sheet5F813CC8 File: led.sch Signal Sheet: sheet5F813D46 File: led.sch Signal Sheet: sheet5F813D9A

File: led.sch Signal Sheet: sheet5F813DD6 File: led.sch Signal Sheet: sheet5F813E3A

Id: 2/27 Title: RS-232 Sniffer File: led8x.sch Sheet: /LEDs A/ HTL-Steyr Prof. Karl Zeilhofer 3AHEL/3BHEL 2020/2021 Github: https://github.com/KarlZeilhofer/rs232-sniffer

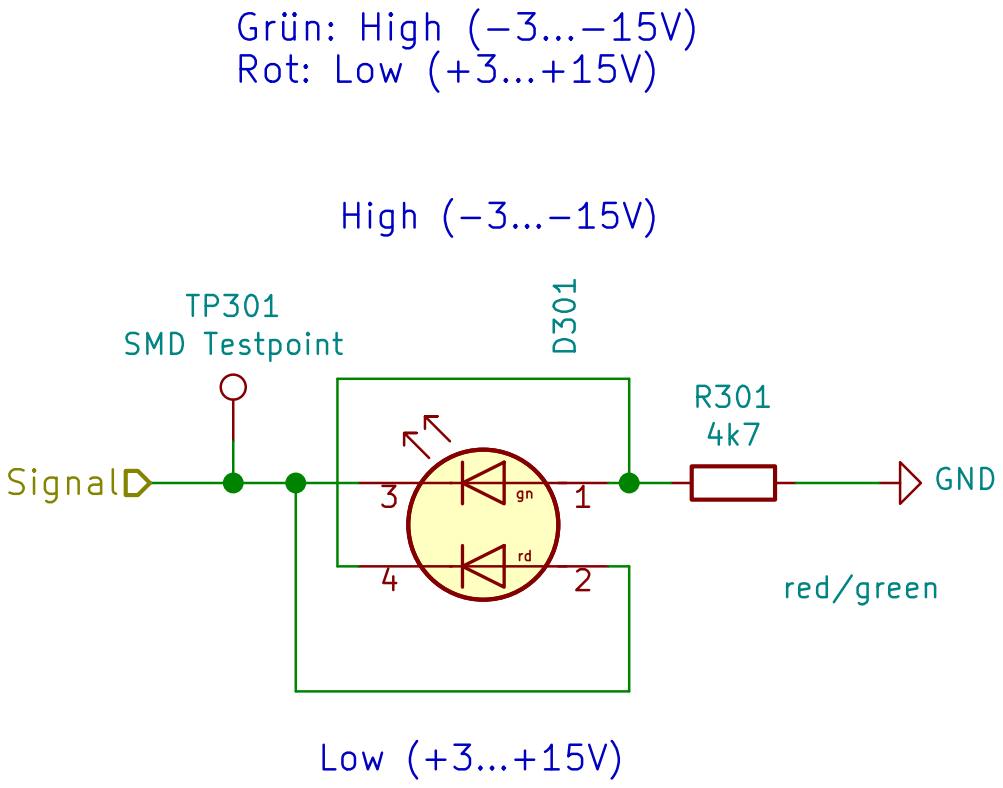
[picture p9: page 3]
D Date: 2020-12-11 KiCad E.D.A. kicad 5.1.6-c6e7f7d87ubuntu18.04.1 Size: A4; Rev: v20.0.0; D³⁰¹; red/green TP301 SMD Testpoint; GND; R301 4k7 Signal; Low (+3...+15V); Grün: High (-3...-15V) Rot: Low (+3...+15V); High (-3...-15V)

Id: 3/27 Title: RS-232 Sniffer File: led.sch Sheet: /LEDs A/sheet5F813BE0/ HTL-Steyr Prof. Karl Zeilhofer 3AHEL/3BHEL 2020/2021 Github: https://github.com/KarlZeilhofer/rs232-sniffer

# 8 9 SW2401 DIP-Switch 8 GND

### DTR

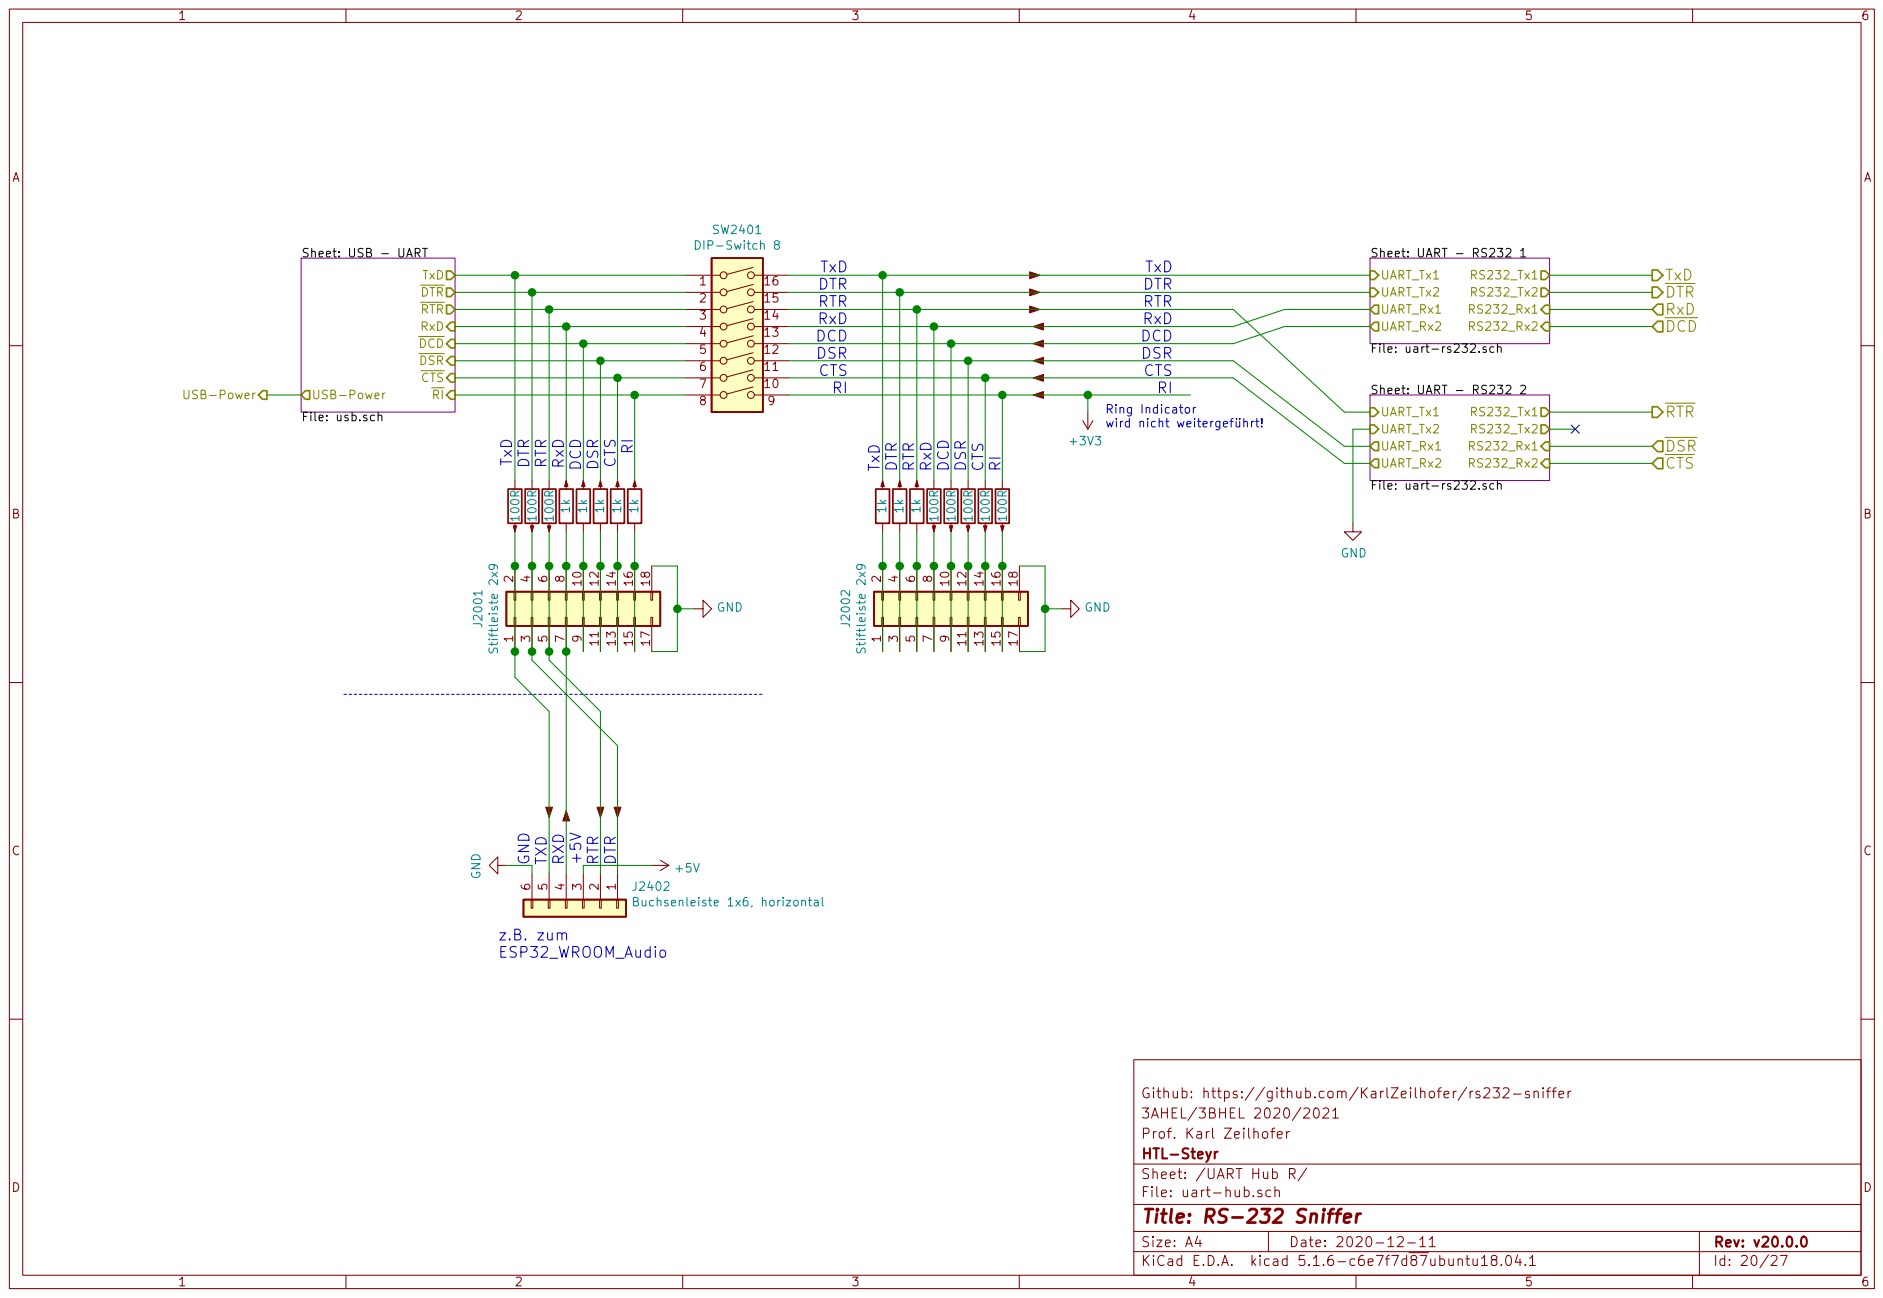
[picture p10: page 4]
D Date: 2020-12-11 KiCad E.D.A. kicad 5.1.6-c6e7f7d87ubuntu18.04.1 Size: A4; Rev: v20.0.0; Sheet: UART - RS232 1 File: uart-rs232.sch UART_Tx1 UART_Tx2 UART_Rx1 UART_Rx2; RS232_Rx2 RS232_Rx1 RS232_Tx2 RS232_Tx1 Sheet: UART - RS232 2 File: uart-rs232.sch UART_Tx1 UART_Tx2 UART_Rx1 UART_Rx2; RS232_Rx2 RS232_Rx1 RS232_Tx2 RS232_Tx1 Sheet: USB - UART; File: usb.sch; TxD; DTR RTR RxD; CTS DSR; RI DCD; USB-Power; GND ¹⁰⁰R 100R 1k1k1k1k1k 100R; J2402 Buchsenleiste 1x6, horizontal ¹⁰⁰R; GND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

TxD
DTR
RTR
RxD
DCD
DSR
CTS
RI TxD DTR RTR RxD DCD DSR CTS RI

RI GND TXD RXD +5V RTR DTR TxD DTR RTR RxD DCD DSR CTSRI

Ring Indicator
wird nicht weitergeführt!

Id: 20/27 Title: RS-232 Sniffer File: uart-hub.sch Sheet: /UART Hub R/ HTL-Steyr Prof. Karl Zeilhofer 3AHEL/3BHEL 2020/2021 Github: https://github.com/KarlZeilhofer/rs232-sniffer

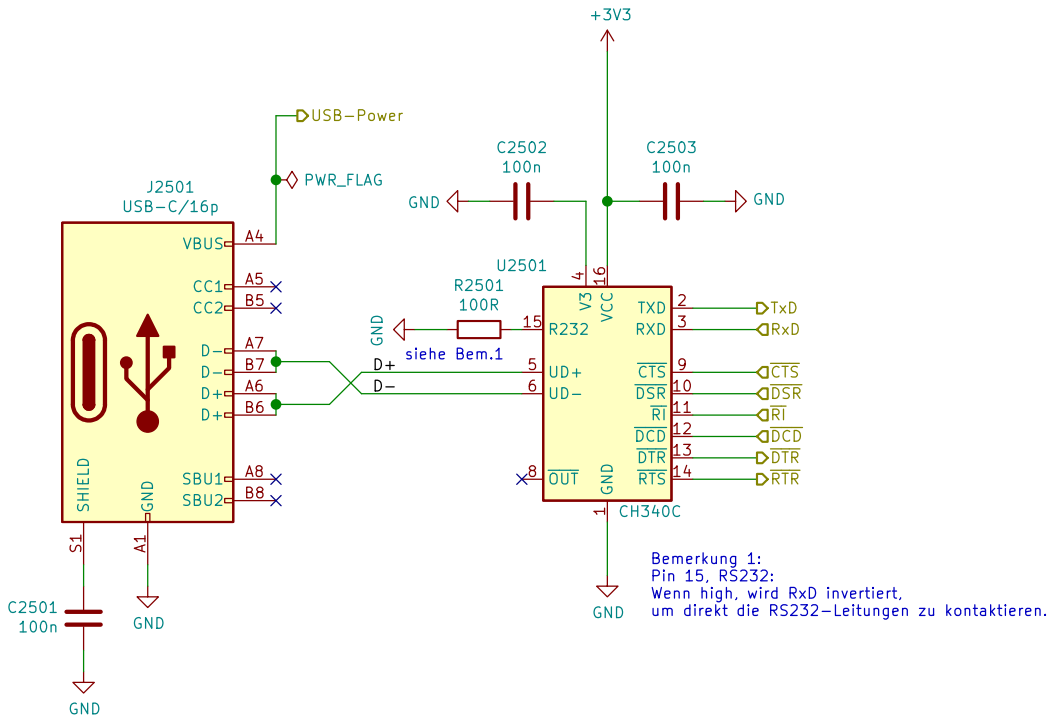
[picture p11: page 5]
D Date: 2020-12-11 KiCad E.D.A. kicad 5.1.6-c6e7f7d87ubuntu18.04.1 Size: A4; Rev: v20.0.0; Id: 21/27 Title: RS-232 Sniffer File: usb.sch Sheet: /UART Hub R/USB - UART/ HTL-Steyr Prof. Karl Zeilhofer 3AHEL/3BHEL 2020/2021 Github: https://github.com/KarlZeilhofer/rs232-sniffer GND; GND; PWR_FLAG; 4 UD+ 5 UD- 6 OUT 8 CTS 9 U2501 CH340C; 100n GND A¹; VBUS; A4 CC1 A5 D+ A6 D- A7 SBU1; A8 CC2 B5 D+ B6 D- B7 SBU2; B8 SHIELD S¹; J2501 USB-C/16p; GND GND; 100n USB-Power; DSR; RI TxD; DTR RTR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

1 DSR 10 RI 11 DCD 12 DTR 13 RTS 14 R232 15 VCC 16 TXD 2 RXD 3 V3

um direkt die RS232-Leitungen zu kontaktieren.

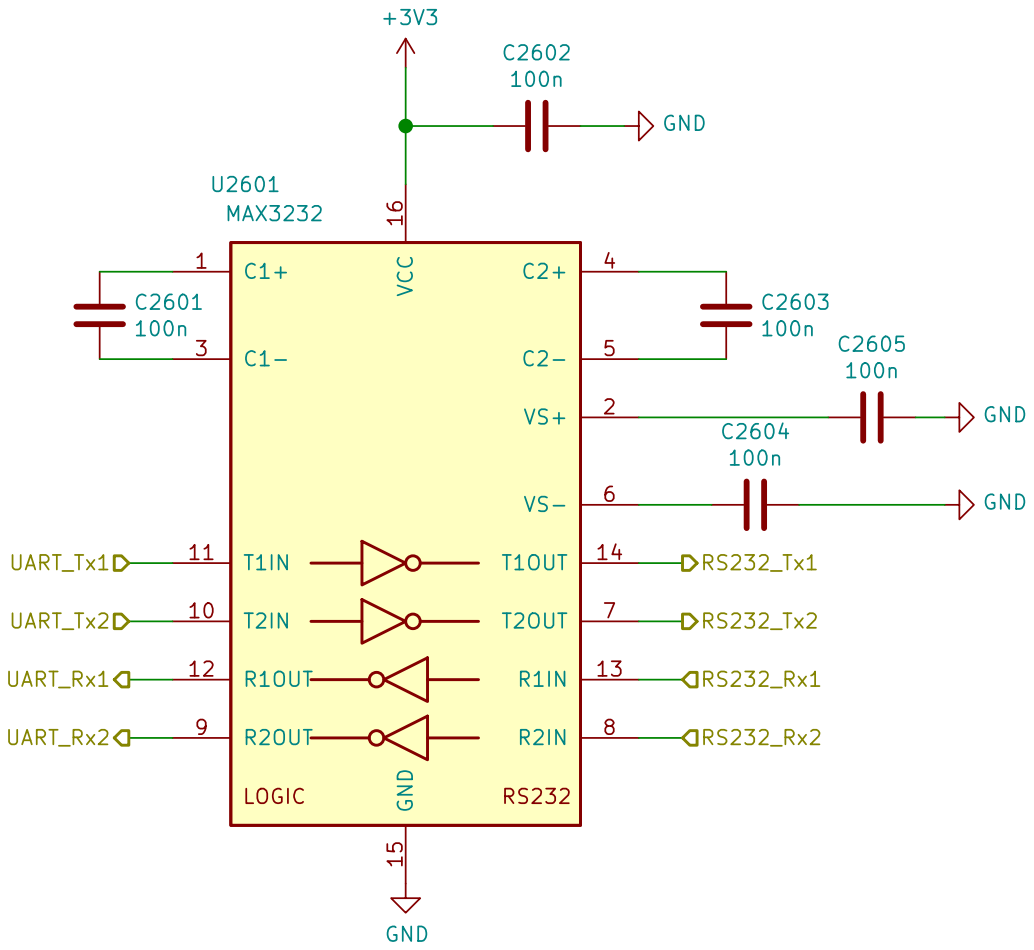
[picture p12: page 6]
D Date: 2020-12-11 KiCad E.D.A. kicad 5.1.6-c6e7f7d87ubuntu18.04.1 Size: A4; Rev: v20.0.0; LOGIC; R1OUT 12; 13 T1OUT; 14 GND 15 VCC ¹⁶; 6 T2OUT; 8 R2OUT 9 U2601 MAX3232; GND; GND GND; RS232_Rx1 RS232_Tx1 RS232_Tx2 UART_Tx1 UART_Rx2; RS232_Rx2 UART_Rx1 UART_Tx2

Id: 22/27 Title: RS-232 Sniffer File: uart-rs232.sch Sheet: /UART Hub R/UART - RS232 1/ HTL-Steyr Prof. Karl Zeilhofer 3AHEL/3BHEL 2020/2021 Github: https://github.com/KarlZeilhofer/rs232-sniffer GND

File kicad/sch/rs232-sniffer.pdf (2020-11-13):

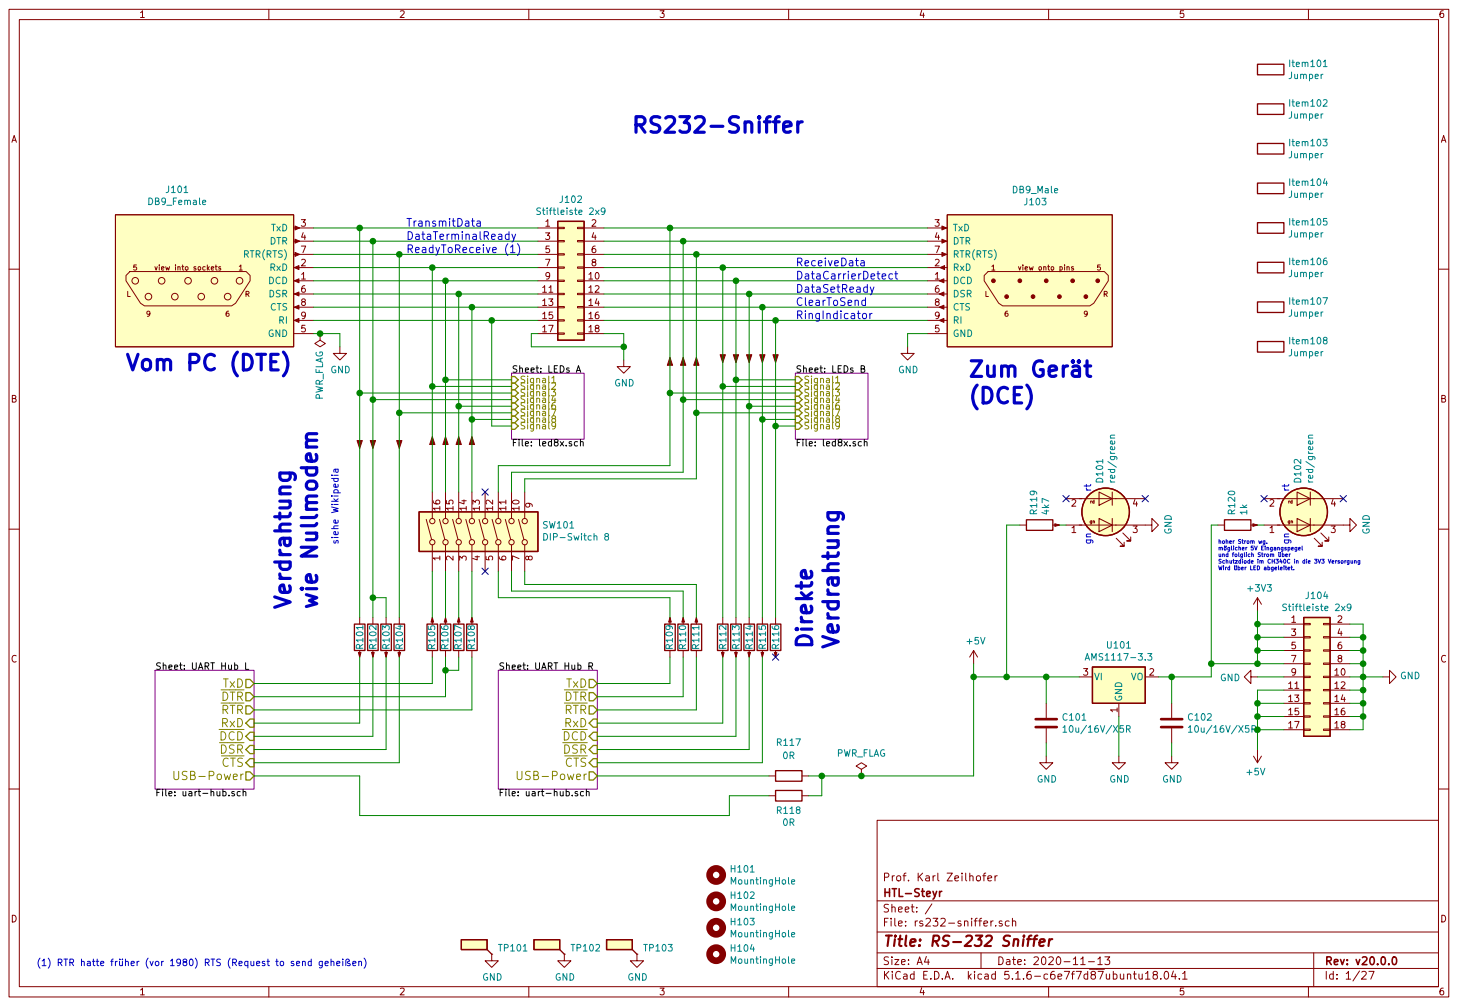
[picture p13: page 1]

DataTerminalReady TransmitData Verdrahtung wie Nullmodem

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

9 | | 10
11 | | 12 | | | | DataSetReady
13 | | 14
15 | | 16 | | | RingIndicator
17 | | 18

USB-Power Sheet: UART Hub L File: uart-hub.schDCD

Id: 1/27 Title: RS-232 Sniffer File: rs232-sniffer.sch Sheet: / HTL-Steyr Prof. Karl Zeilhofer Sheet: UART Hub R

13 | 14
15 | 16
17 | 18

File: uart-hub.schDCD

(1) RTR hatte früher (vor 1980) RTS (Request to send geheißen)


File: led.sch Signal Sheet: sheet5F813E84 File: led.sch Signal Sheet: sheet5F813BE0 File: led.sch Signal

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

File: led.sch Signal Sheet: sheet5F813DD6 File: led.sch Signal Sheet: sheet5F813E3A

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

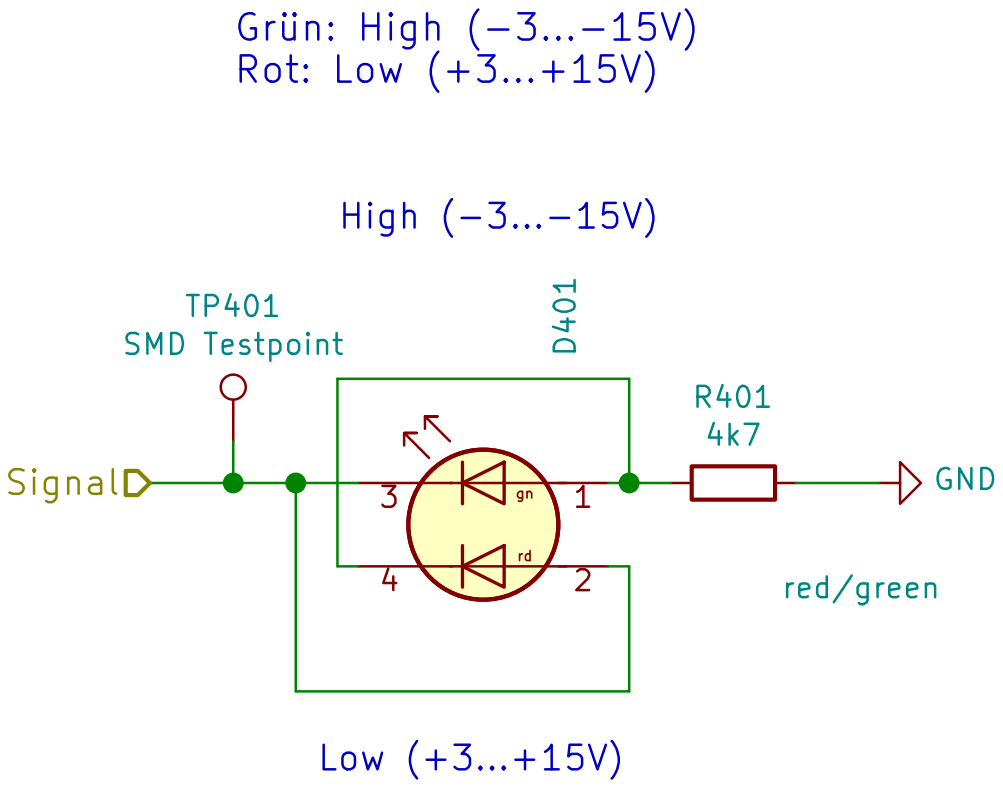
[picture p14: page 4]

Id: 4/27 Title: RS-232 Sniffer File: led.sch Sheet: /LEDs A/sheet5F813C62/ HTL-Steyr Prof. Karl Zeilhofer

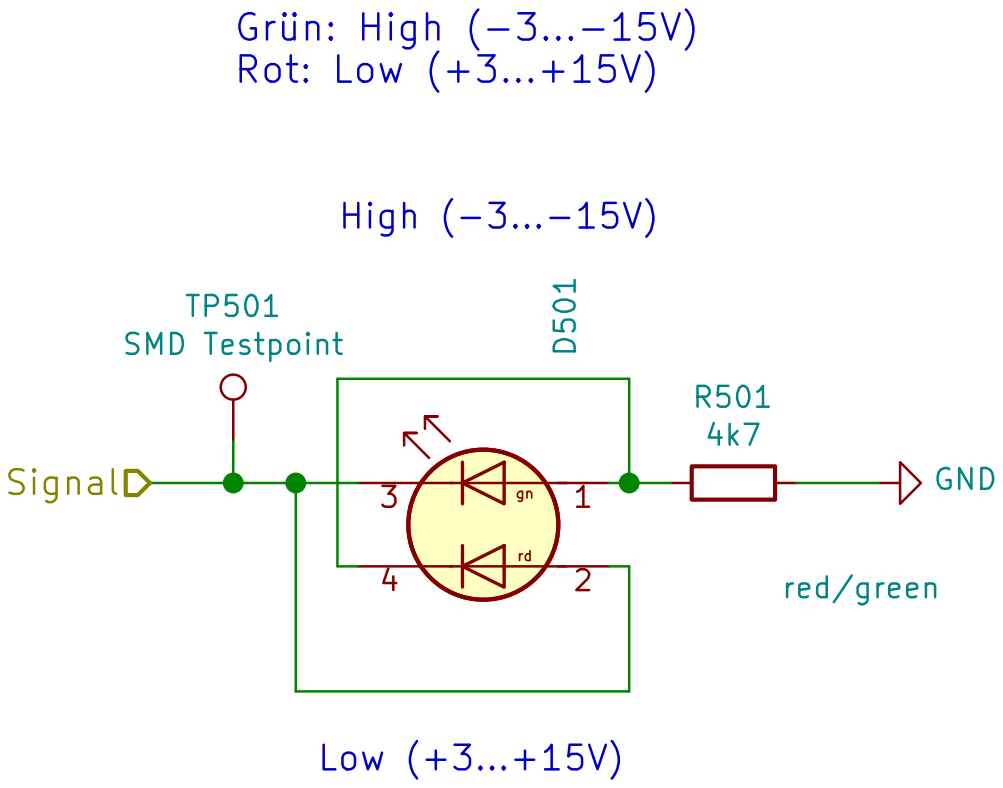
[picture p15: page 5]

Id: 5/27 Title: RS-232 Sniffer File: led.sch Sheet: /LEDs A/sheet5F813CC8/ HTL-Steyr Prof. Karl Zeilhofer

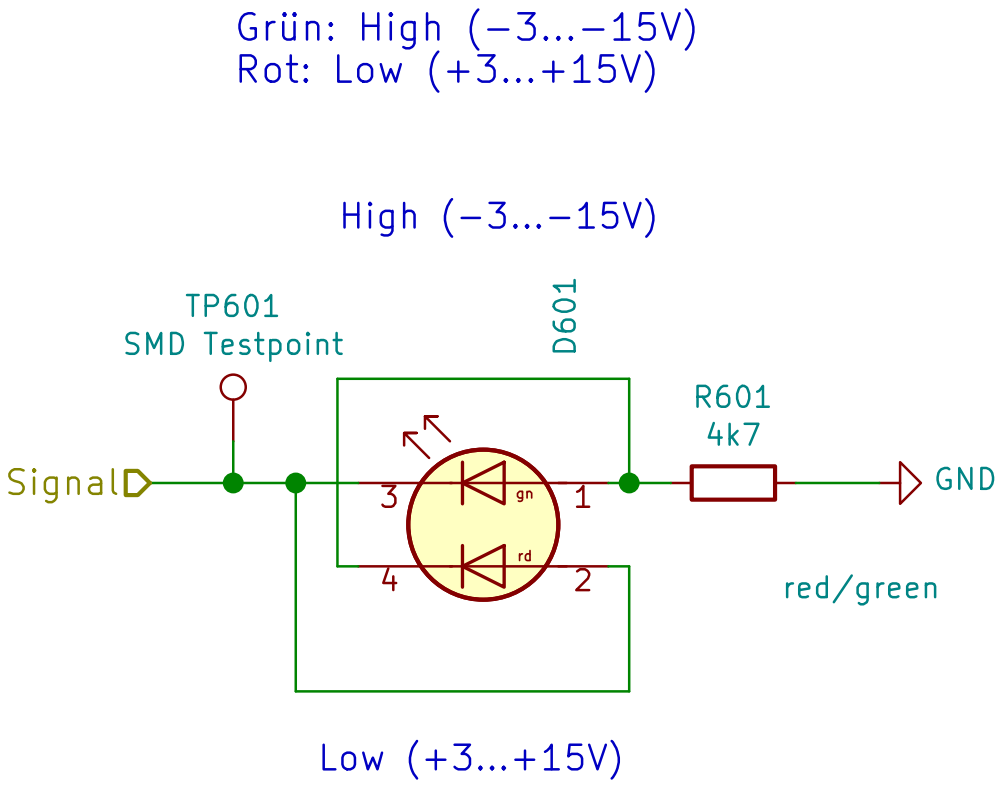
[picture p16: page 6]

Id: 6/27 Title: RS-232 Sniffer File: led.sch Sheet: /LEDs A/sheet5F813D46/ HTL-Steyr Prof. Karl Zeilhofer

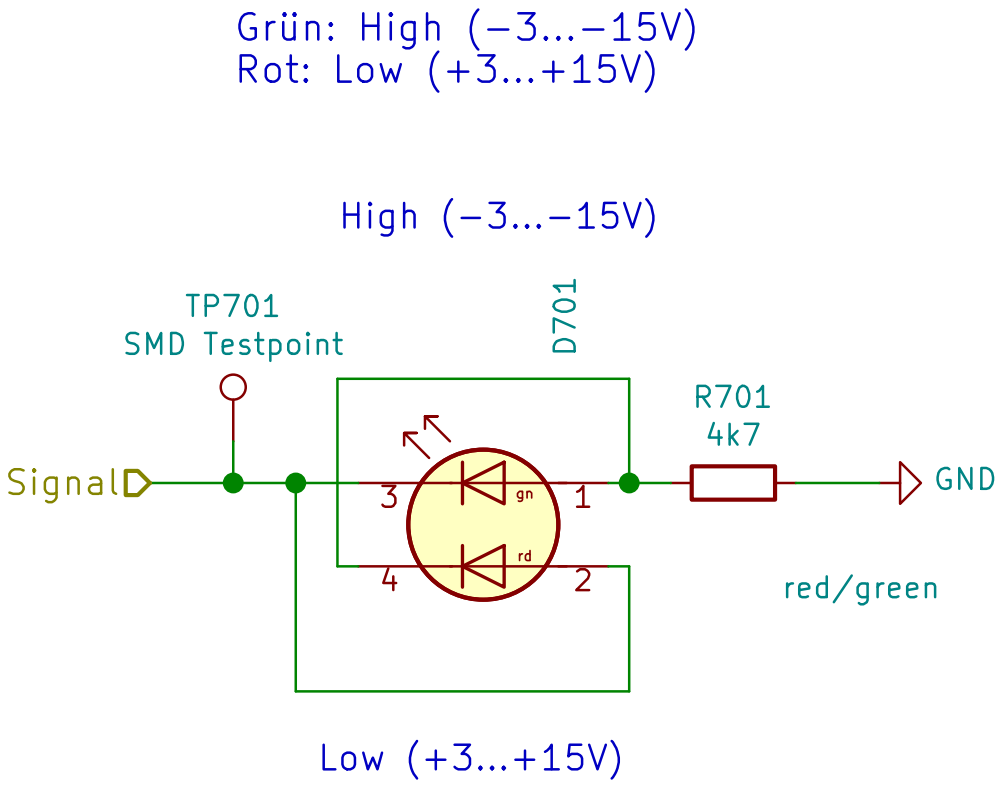
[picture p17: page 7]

Id: 7/27 Title: RS-232 Sniffer File: led.sch Sheet: /LEDs A/sheet5F813D9A/ HTL-Steyr Prof. Karl Zeilhofer

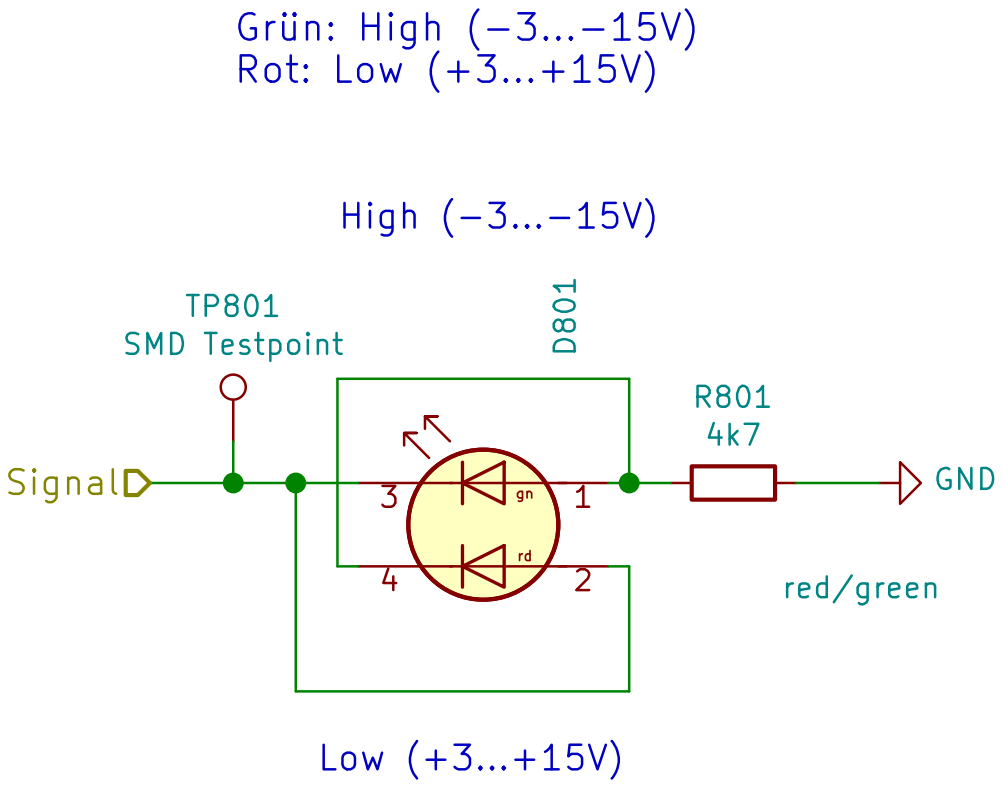
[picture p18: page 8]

Id: 8/27 Title: RS-232 Sniffer File: led.sch Sheet: /LEDs A/sheet5F813DD6/ HTL-Steyr Prof. Karl Zeilhofer


Id: 9/27 Title: RS-232 Sniffer File: led.sch Sheet: /LEDs A/sheet5F813E3A/ HTL-Steyr Prof. Karl Zeilhofer


Id: 10/27 Title: RS-232 Sniffer File: led.sch Sheet: /LEDs A/sheet5F813E84/ HTL-Steyr Prof. Karl Zeilhofer

File: led.sch Signal Sheet: sheet5F813E84 File: led.sch Signal Sheet: sheet5F813BE0 File: led.sch Signal

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

File: led.sch Signal Sheet: sheet5F813DD6 File: led.sch Signal Sheet: sheet5F813E3A

Id: 11/27 Title: RS-232 Sniffer File: led8x.sch Sheet: /LEDs B/ HTL-Steyr Prof. Karl Zeilhofer


Id: 12/27 Title: RS-232 Sniffer File: led.sch Sheet: /LEDs B/sheet5F813BE0/ HTL-Steyr Prof. Karl Zeilhofer


Id: 13/27 Title: RS-232 Sniffer File: led.sch Sheet: /LEDs B/sheet5F813C62/ HTL-Steyr Prof. Karl Zeilhofer

Id: 14/27 Title: RS-232 Sniffer File: led.sch Sheet: /LEDs B/sheet5F813CC8/ HTL-Steyr Prof. Karl Zeilhofer


Id: 15/27 Title: RS-232 Sniffer File: led.sch Sheet: /LEDs B/sheet5F813D46/ HTL-Steyr Prof. Karl Zeilhofer


Id: 16/27 Title: RS-232 Sniffer File: led.sch Sheet: /LEDs B/sheet5F813D9A/ HTL-Steyr Prof. Karl Zeilhofer


Id: 17/27 Title: RS-232 Sniffer File: led.sch Sheet: /LEDs B/sheet5F813DD6/ HTL-Steyr Prof. Karl Zeilhofer


Id: 18/27 Title: RS-232 Sniffer File: led.sch Sheet: /LEDs B/sheet5F813E3A/ HTL-Steyr Prof. Karl Zeilhofer


Id: 19/27 Title: RS-232 Sniffer File: led.sch Sheet: /LEDs B/sheet5F813E84/ HTL-Steyr Prof. Karl Zeilhofer


TxD
DTR
RTR
RxD
DCD
DSR
CTS
RI TxD DTR RTR RxD DCD DSR CTS RI

RI GND TXD RXD +5V RTR DTR TxD DTR RTR RxD DCD DSR CTSRI

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

um direkt die RS232-Leitungen zu kontaktieren.


Id: 22/27 Title: RS-232 Sniffer File: uart-rs232.sch Sheet: /UART Hub R/UART - RS232 1/ HTL-Steyr Prof. Karl Zeilhofer GND

Id: 23/27 Title: RS-232 Sniffer File: uart-rs232.sch Sheet: /UART Hub R/UART - RS232 2/ HTL-Steyr Prof. Karl Zeilhofer GND


TxD
DTR
RTR
RxD
DCD
DSR
CTS
RI TxD DTR RTR RxD DCD DSR CTS RI

RI GND TXD RXD +5V RTR DTR TxD DTR RTR RxD DCD DSR CTSRI
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


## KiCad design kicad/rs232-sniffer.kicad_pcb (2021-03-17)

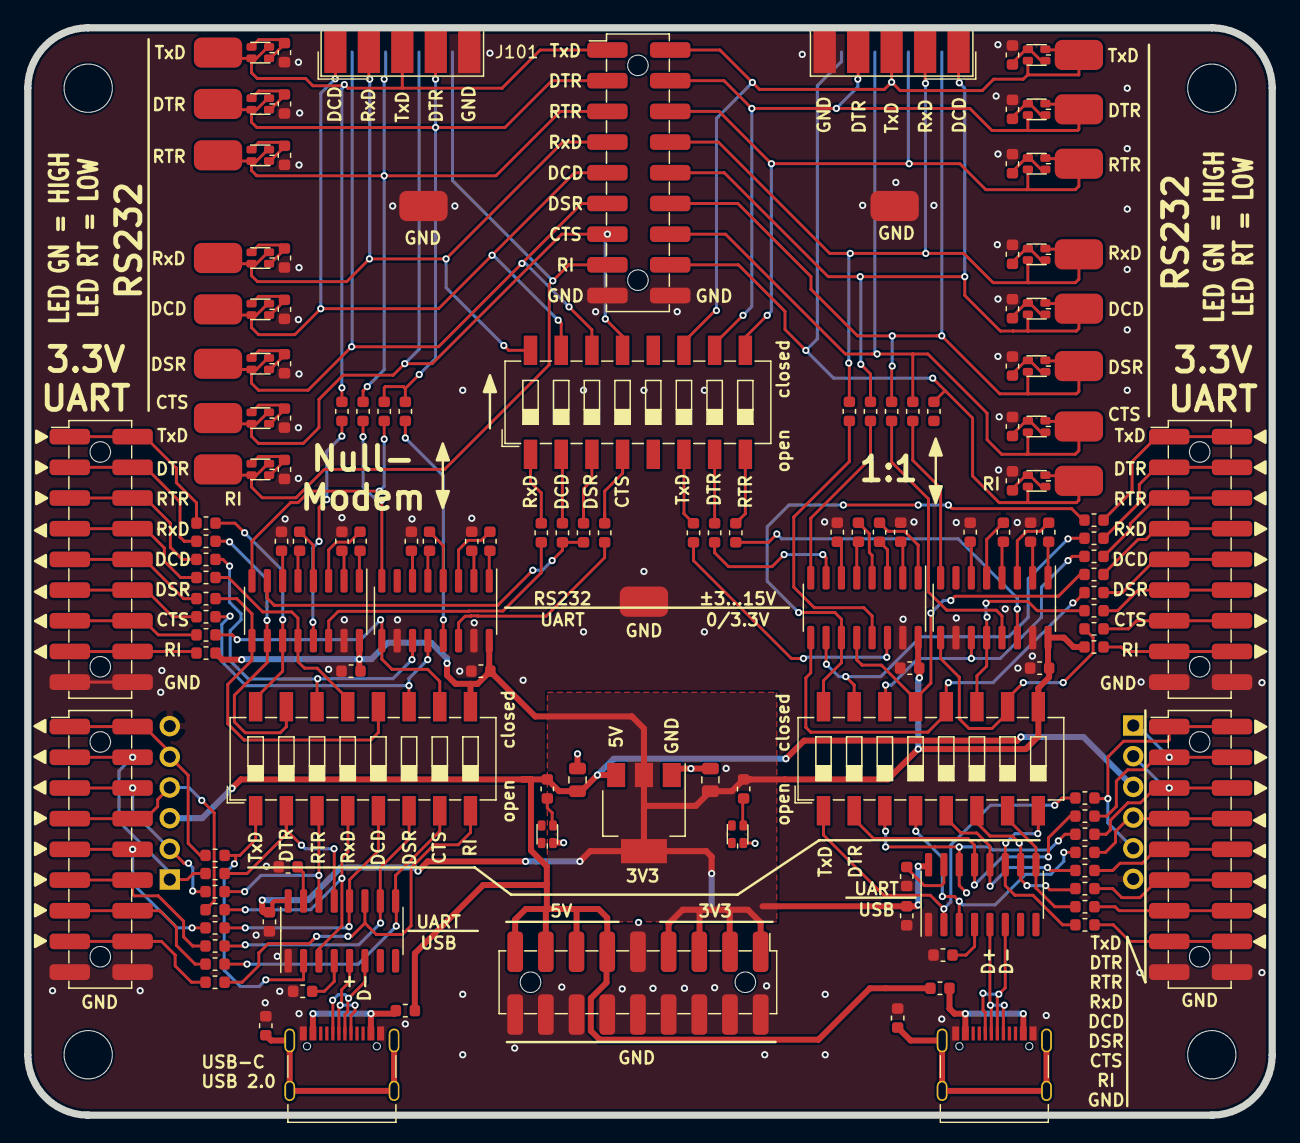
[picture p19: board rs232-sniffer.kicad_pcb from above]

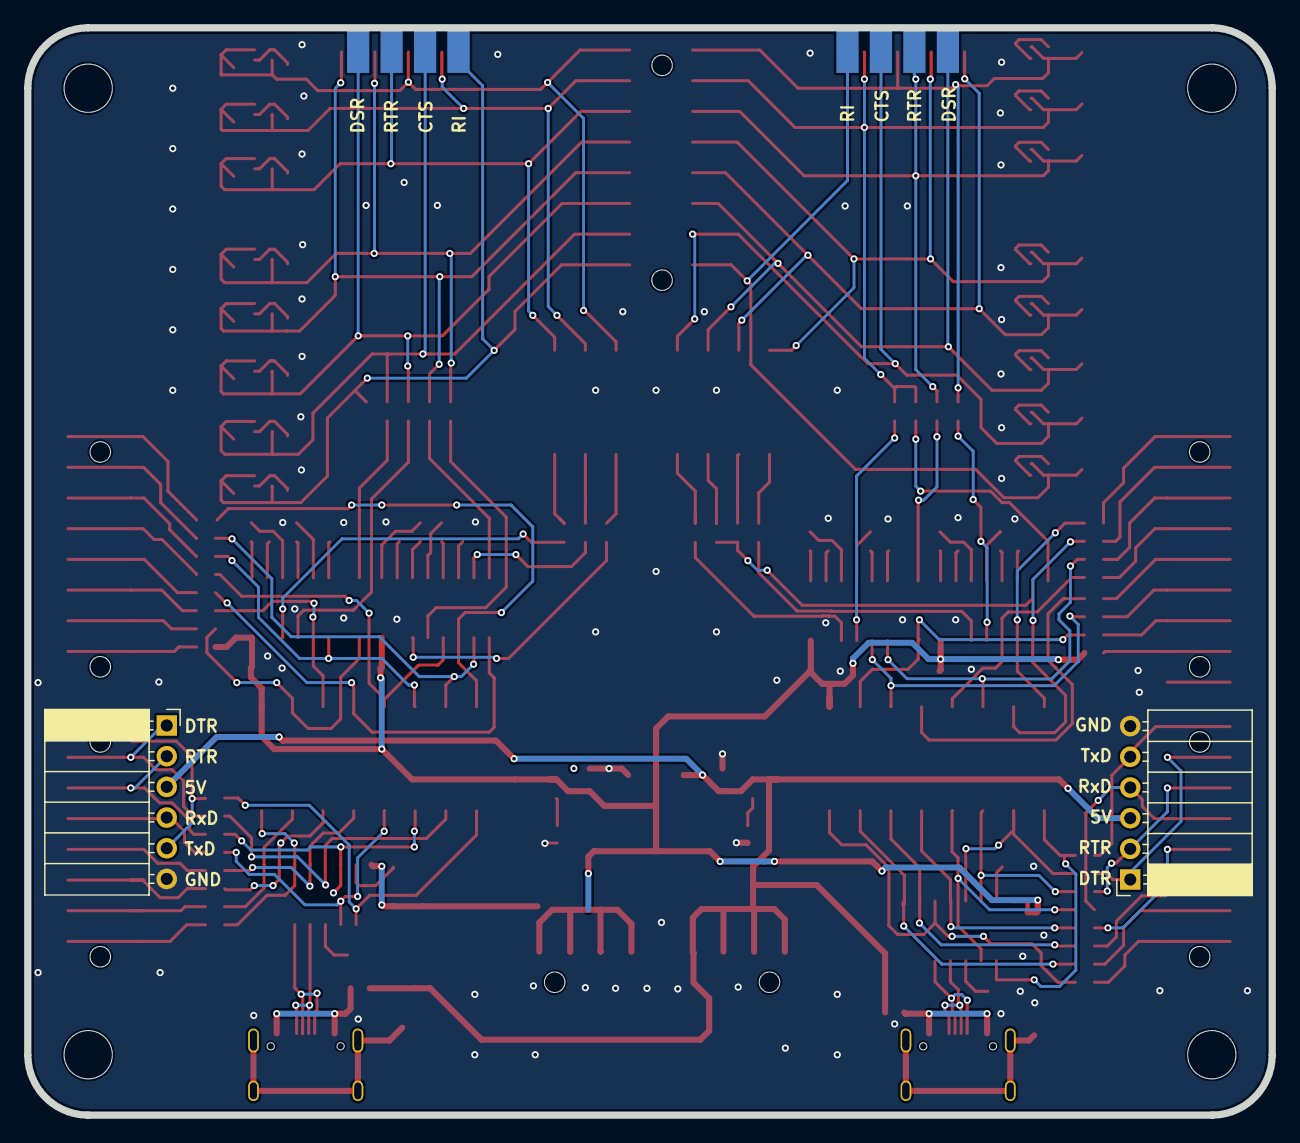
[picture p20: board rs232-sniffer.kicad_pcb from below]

Board: 2 copper layers, 103.0 x 90.0 mm, 161 parts (2 on the bottom side), 156 nets.

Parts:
C101, C102: 10u/16V/X5R; C_0805_2012Metric
C2501, C2502, C2503, C2504, C2505, C2506, C2601, C2602, C2603, C2604, C2605, C2606, C2607, C2608, C2609, C2610, C2701, C2702, C2703, C2704, C2705, C2706, C2707, C2708, C2709, C2710: 100n; C_0603_1608Metric
D101, D102, D301, D401, D501, D601, D701, D801, D901, D1001, D1201, D1301, D1401, D1501, D1601, D1701, D1801, D1901: red/green; LED_LiteOn_LTST-C195KGJRKT
H101, H102, H103, H104: MountingHole; MountingHole_4mm
J101: DB9_Female; DSUB-9_Female_EdgeMount_P2.77mm
J102, J104, J2001, J2002, J2401, J2403: Stiftleiste 2x9; PinHeader_2x09_P2.54mm_Vertical_SMD_LCSC_C88175
J103: DB9_Male; DSUB-9_Male_EdgeMount_P2.77mm
J2402, J2405: Buchsenleiste 1x6, horizontal; PinSocket_1x06_P2.54mm_Horizontal
J2501, J2502: USB-C/16p; USB_C_Receptacle_LCSC_C167321
R101, R102, R103, R104, R105, R106, R107, R108, R109, R110, R111, R112, R113, R114, R115, R116, R2004, R2005, R2006, R2007, R2008, R2403, R2404, R2406, R2409, R2410, R2411, R2420, R2421, R2422, R2423, R2424, R2501, R2502: 100R; R_0603_1608Metric
R117, R118: 0R; R_0603_1608Metric
R119, R301, R401, R501, R601, R701, R801, R901, R1001, R1201, R1301, R1401, R1501, R1601, R1701, R1801, R1901: 4k7; R_0603_1608Metric
R120, R2001, R2002, R2003, R2401, R2402, R2405, R2407, R2408, R2412, R2413, R2414, R2415, R2416, R2417, R2418, R2419: 1k; R_0603_1608Metric
SW101, SW2401, SW2402: DIP-Switch 8; SW_DIP_SPSTx08_Slide_6.7x21.88mm_W8.61mm_P2.54mm_LowProfile
TP101, TP102, TP103, TP301, TP401, TP501, TP601, TP701, TP801, TP901, TP1001, TP1201, TP1301, TP1401, TP1501, TP1601, TP1701, TP1801, TP1901: SMD Testpoint; Keystone_5016
U101: AMS1117-3.3; SOT-223-3_TabPin2
U2501, U2502: CH340C; SOIC-16_3.9x9.9mm_P1.27mm
U2601, U2602, U2701, U2702: MAX3232; SOIC-16_3.9x9.9mm_P1.27mm

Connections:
+3V3: C102.1, C2503.2, C2506.2, C2602.2, C2607.2, C2702.2, C2707.2, J104.1, J104.3, J104.5, J104.7, R120.1, R2008.1, R2424.1, SW2401.9, SW2402.9, U101.2, U2501.16, U2502.16, U2601.16, U2602.16, U2701.16, U2702.16
+5V: C101.1, J104.11, J104.13, J104.15, J104.17, J2402.3, J2405.3, R117.2, R118.2, R119.1, U101.3
/LEDs A/Signal1: D301.2, D301.3, J101.1, J102.9, SW101.15, TP301.1
/LEDs A/Signal2: D401.2, D401.3, J101.2, J102.7, SW101.16, TP401.1
/LEDs A/Signal3: D501.2, D501.3, J101.3, J102.1, R101.1, TP501.1
/LEDs A/Signal4: D601.2, D601.3, J101.4, J102.3, R102.1, R103.1, TP601.1
/LEDs A/Signal6: D701.2, D701.3, J101.6, J102.11, SW101.14, TP701.1
/LEDs A/Signal7: D801.2, D801.3, J101.7, J102.5, R104.1, TP801.1
/LEDs A/Signal8: D901.2, D901.3, J101.8, J102.13, SW101.13, TP901.1
/LEDs A/Signal9: D1001.2, D1001.3, J101.9, J102.15, TP1001.1
/LEDs B/Signal1: D1201.2, D1201.3, J102.10, J103.1, R113.1, TP1201.1
/LEDs B/Signal2: D1301.2, D1301.3, J102.8, J103.2, R112.1, TP1301.1
/LEDs B/Signal3: D1401.2, D1401.3, J102.2, J103.3, SW101.11, TP1401.1
/LEDs B/Signal4: D1501.2, D1501.3, J102.4, J103.4, SW101.10, TP1501.1
/LEDs B/Signal6: D1601.2, D1601.3, J102.12, J103.6, R114.1, TP1601.1
/LEDs B/Signal7: D1701.2, D1701.3, J102.6, J103.7, SW101.9, TP1701.1
/LEDs B/Signal8: D1801.2, D1801.3, J102.14, J103.8, R115.1, TP1801.1
/LEDs B/Signal9: D1901.2, D1901.3, J102.16, J103.9, R116.1, TP1901.1
/UART Hub L/RxD: R101.2, U2602.13
/UART Hub L/TxD: R105.1, U2602.14
/UART Hub L/UART - RS232 1/UART_Rx1: R2420.1, SW2402.13, U2602.12
/UART Hub L/UART - RS232 1/UART_Rx2: R2421.1, SW2402.12, U2602.9
/UART Hub L/UART - RS232 1/UART_Tx1: R2417.2, SW2402.16, U2602.11
/UART Hub L/UART - RS232 1/UART_Tx2: R2418.2, SW2402.15, U2602.10
/UART Hub L/UART - RS232 2/UART_Rx1: R2422.1, SW2402.11, U2702.12
/UART Hub L/UART - RS232 2/UART_Rx2: R2423.1, SW2402.10, U2702.9
/UART Hub L/UART - RS232 2/UART_Tx1: R2419.2, SW2402.14, U2702.11
/UART Hub L/USB - UART/D+: J2502.A6, J2502.B6, U2502.5
/UART Hub L/USB - UART/D-: J2502.A7, J2502.B7, U2502.6
/UART Hub L/USB - UART/RxD: R2412.2, SW2402.4, U2502.3
/UART Hub L/USB - UART/TxD: R2409.1, SW2402.1, U2502.2
/UART Hub L/USB - UART/~CTS: R2415.2, SW2402.7, U2502.9
/UART Hub L/USB - UART/~DCD: R2413.2, SW2402.5, U2502.12
/UART Hub L/USB - UART/~DSR: R2414.2, SW2402.6, U2502.10
/UART Hub L/USB - UART/~DTR: R2410.1, SW2402.2, U2502.13
/UART Hub L/USB - UART/~RI: R2416.2, SW2402.8, U2502.11
/UART Hub L/USB - UART/~RTR: R2411.1, SW2402.3, U2502.14
/UART Hub L/USB-Power: J2502.A4, J2502.A9, J2502.B4, J2502.B9, R118.1
/UART Hub L/~CTS: R104.2, U2702.8
/UART Hub L/~DCD: R102.2, U2602.8
/UART Hub L/~DSR: R103.2, U2702.13
/UART Hub L/~DTR: R106.1, R107.1, U2602.7
/UART Hub L/~RTR: R108.1, U2702.14
/UART Hub R/RxD: R112.2, U2601.13
/UART Hub R/TxD: R109.1, U2601.14
/UART Hub R/UART - RS232 1/UART_Rx1: R2004.1, SW2401.13, U2601.12
/UART Hub R/UART - RS232 1/UART_Rx2: R2005.1, SW2401.12, U2601.9
/UART Hub R/UART - RS232 1/UART_Tx1: R2001.2, SW2401.16, U2601.11
/UART Hub R/UART - RS232 1/UART_Tx2: R2002.2, SW2401.15, U2601.10
/UART Hub R/UART - RS232 2/UART_Rx1: R2006.1, SW2401.11, U2701.12
/UART Hub R/UART - RS232 2/UART_Rx2: R2007.1, SW2401.10, U2701.9
/UART Hub R/UART - RS232 2/UART_Tx1: R2003.2, SW2401.14, U2701.11
/UART Hub R/USB - UART/D+: J2501.A6, J2501.B6, U2501.5
/UART Hub R/USB - UART/D-: J2501.A7, J2501.B7, U2501.6
/UART Hub R/USB - UART/RxD: R2401.2, SW2401.4, U2501.3
/UART Hub R/USB - UART/TxD: R2406.1, SW2401.1, U2501.2
/UART Hub R/USB - UART/~CTS: R2407.2, SW2401.7, U2501.9
/UART Hub R/USB - UART/~DCD: R2402.2, SW2401.5, U2501.12
/UART Hub R/USB - UART/~DSR: R2405.2, SW2401.6, U2501.10
/UART Hub R/USB - UART/~DTR: R2403.1, SW2401.2, U2501.13
/UART Hub R/USB - UART/~RI: R2408.2, SW2401.8, U2501.11
/UART Hub R/USB - UART/~RTR: R2404.1, SW2401.3, U2501.14
/UART Hub R/USB-Power: J2501.A4, J2501.A9, J2501.B4, J2501.B9, R117.1
/UART Hub R/~CTS: R115.2, U2701.8
/UART Hub R/~DCD: R113.2, U2601.8
/UART Hub R/~DSR: R114.2, U2701.13
/UART Hub R/~DTR: R110.1, U2601.7
/UART Hub R/~RTR: R111.1, U2701.14
GND: C101.2, C102.2, C2501.1, C2502.2, C2503.1, C2504.1, C2505.2, C2506.1, C2602.1, C2604.1, C2605.1, C2607.1, C2609.1, C2610.1, C2702.1, C2704.1, C2705.1, C2707.1, C2709.1, C2710.1, D101.3, D102.3, J101.5, J102.17, J102.18, J103.5, J104.2, J104.4, J104.6, J104.8, J104.9, J104.10, J104.12, J104.14, J104.16, J104.18, J2001.17, J2001.18, J2002.17, J2002.18, J2401.17, J2401.18, J2402.6, J2403.17, J2403.18, J2405.6, J2501.A1, J2501.A12, J2501.B1, J2501.B12, J2502.A1, J2502.A12, J2502.B1, J2502.B12, R301.2, R401.2, R501.2, R601.2, R701.2, R801.2, R901.2, R1001.2, R1201.2, R1301.2, R1401.2, R1501.2, R1601.2, R1701.2, R1801.2, R1901.2, R2501.2, R2502.2, TP101.1, TP102.1, TP103.1, U101.1, U2501.1, U2502.1, U2601.15, U2602.15, U2701.10, U2701.15, U2702.10, U2702.15
unnamed: C2501.2, J2501.S1
unnamed: C2502.1, U2501.4
unnamed: C2504.2, J2502.S1
unnamed: C2505.1, U2502.4
unnamed: C2601.1, U2601.1
unnamed: C2601.2, U2601.3
unnamed: C2603.1, U2601.4
unnamed: C2603.2, U2601.5
unnamed: C2604.2, U2601.6
unnamed: C2605.2, U2601.2
unnamed: C2606.1, U2602.1
unnamed: C2606.2, U2602.3
unnamed: C2608.1, U2602.4
unnamed: C2608.2, U2602.5
unnamed: C2609.2, U2602.6
unnamed: C2610.2, U2602.2
unnamed: C2701.1, U2701.1
unnamed: C2701.2, U2701.3
unnamed: C2703.1, U2701.4
unnamed: C2703.2, U2701.5
unnamed: C2704.2, U2701.6
unnamed: C2705.2, U2701.2
unnamed: C2706.1, U2702.1
unnamed: C2706.2, U2702.3
unnamed: C2708.1, U2702.4
unnamed: C2708.2, U2702.5
unnamed: C2709.2, U2702.6
unnamed: C2710.2, U2702.2
unnamed: D101.1, R119.2
unnamed: D102.1, R120.2
unnamed: D301.1, D301.4, R301.1
unnamed: D401.1, D401.4, R401.1
unnamed: D501.1, D501.4, R501.1
unnamed: D601.1, D601.4, R601.1
unnamed: D701.1, D701.4, R701.1
unnamed: D801.1, D801.4, R801.1
unnamed: D901.1, D901.4, R901.1
unnamed: D1001.1, D1001.4, R1001.1
unnamed: D1201.1, D1201.4, R1201.1
unnamed: D1301.1, D1301.4, R1301.1
unnamed: D1401.1, D1401.4, R1401.1
unnamed: D1501.1, D1501.4, R1501.1
unnamed: D1601.1, D1601.4, R1601.1
unnamed: D1701.1, D1701.4, R1701.1
unnamed: D1801.1, D1801.4, R1801.1
unnamed: D1901.1, D1901.4, R1901.1
unnamed: J2001.1, J2001.2, J2402.5, R2406.2
unnamed: J2001.3, J2001.4, J2402.1, R2403.2
unnamed: J2001.5, J2001.6, J2402.2, R2404.2
unnamed: J2001.7, J2001.8, J2402.4, R2401.1
unnamed: J2001.9, J2001.10, R2402.1
unnamed: J2001.11, J2001.12, R2405.1
unnamed: J2001.13, J2001.14, R2407.1
unnamed: J2001.15, J2001.16, R2408.1
unnamed: J2002.1, J2002.2, R2001.1
unnamed: J2002.3, J2002.4, R2002.1
unnamed: J2002.5, J2002.6, R2003.1
unnamed: J2002.7, J2002.8, R2004.2
unnamed: J2002.9, J2002.10, R2005.2
unnamed: J2002.11, J2002.12, R2006.2
unnamed: J2002.13, J2002.14, R2007.2
unnamed: J2002.15, J2002.16, R2008.2
unnamed: J2401.1, J2401.2, J2405.5, R2409.2
unnamed: J2401.3, J2401.4, J2405.1, R2410.2
unnamed: J2401.5, J2401.6, J2405.2, R2411.2
unnamed: J2401.7, J2401.8, J2405.4, R2412.1
unnamed: J2401.9, J2401.10, R2413.1
unnamed: J2401.11, J2401.12, R2414.1
unnamed: J2401.13, J2401.14, R2415.1
unnamed: J2401.15, J2401.16, R2416.1
unnamed: J2403.1, J2403.2, R2417.1
unnamed: J2403.3, J2403.4, R2418.1
unnamed: J2403.5, J2403.6, R2419.1
unnamed: J2403.7, J2403.8, R2420.2
unnamed: J2403.9, J2403.10, R2421.2
unnamed: J2403.11, J2403.12, R2422.2
unnamed: J2403.13, J2403.14, R2423.2
unnamed: J2403.15, J2403.16, R2424.2
unnamed: R105.2, SW101.1
unnamed: R106.2, SW101.2
unnamed: R107.2, SW101.3
unnamed: R108.2, SW101.4
unnamed: R109.2, SW101.6
unnamed: R110.2, SW101.7
unnamed: R111.2, SW101.8
unnamed: R2501.1, U2501.15
unnamed: R2502.1, U2502.15

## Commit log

2019-12-16 erste version zeilhofer
    [led.sch, rs232-sniffer.kicad_pcb, rs232-sniffer.sch]
2019-12-16 version marius wasinger
    [61800924823_Download_STP_61800924823_rev1.stp, 61800924923_Download_STP_61800924923_rev1.stp, 61800925123_Downloads_STP_61800925123_rev1.stp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]
2019-12-16 3D files Testpunkt
    [keystone-5029.FCStd, keystone-5029.step, keystone_5029.FCStd]
2020-11-11 übergabe an 3ahel
    [61800924823_Download_STP_61800924823_rev1.stp, 61800924923_Download_STP_61800924923_rev1.stp, 61800925123_Downloads_STP_61800925123_rev1.stp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]
2020-11-11 Layout fast fertig Footprint für 2x9-polig wurde aktualisiert
    [rs232-sniffer.kicad_pcb, rs232-sniffer.sch, uart-hub.sch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]
2020-11-12 manual merge with master
    [kalkulation.ods, led.sch, led8x.sch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]
2020-11-13 fertig geroutet
    [rs232-sniffer.kicad_pcb, uart-hub.sch, uart-rs232.sch]
2020-11-13 V20.0.0 fertig zur Leiterplattenbestellung, BOM export, PDF, Gerber
    [led.sch, led8x.sch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]
2021-03-15 rework gestartet
    [rs232-sniffer.kicad_pcb, usb.sch]
2021-03-17 Keine SMD-Paste bei den Steckverbindern
    [rs232-sniffer.kicad_pcb]
2021-03-17 v20.0.1 fertig, 30 Stk bestellt
    [rs232-sniffer-B_Cu.gbr, rs232-sniffer-B_Mask.gbr, rs232-sniffer-B_SilkS.gbr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]
2021-03-26 HTML BOM V20.0.1
2021-09-29 BOM vervollständigt
    [rs232-sniffer.sch, uart-hub.sch]
